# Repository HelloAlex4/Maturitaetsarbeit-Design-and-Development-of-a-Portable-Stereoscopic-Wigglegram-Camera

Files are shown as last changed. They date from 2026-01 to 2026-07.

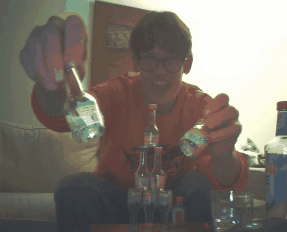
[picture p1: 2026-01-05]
sample_Images/wigglegram1.gif

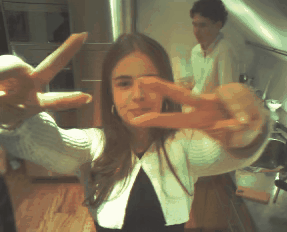
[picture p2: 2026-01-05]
sample_Images/wigglegram3.gif

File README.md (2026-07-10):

# Design and Development of a Portable Stereoscopic Wigglegram Camera

### !!!THIS IS NOT THE CURRENT VERSION OF MERGED.CAMERA, YOU SHOULD NOT COPY THIS BUILD!!!

**Author:** Alexander Rieser

**Project Type:** Maturitätsarbeit (25/26)

**Supervisor:** Madlaina Holler

**Expert:** Patrick Habegger

## Abstract

This Maturitätsarbeit details the design, development, and implementation of a custom-built, portable stereoscopic camera capable of capturing animated wigglegrams. While the wigglegram effect has traditionally been limited to specialized analog film cameras or bulky adapters, this project represents the world's first digital wigglegram camera outside of a few private prototypes. The camera utilizes four horizontally aligned camera modules controlled by multiple processors to capture the wigglegrams. The device surpasses most of its initial goals, such as a synchronization between the first and last camera capture of less than 16 ms. This document extensively details both the technical architecture of the device and the development process. Despite multiple identified limitations like the image resolution and quality, the final product serves as a successful proof-of-concept and a baseline for further improvement.

## Project Overview

This project aims to fill a gap in the market by providing a self-contained, handheld device capable of capturing and processing digital stereoscopic images (wigglegrams) without the need for analog film or bulky adapters. The camera captures four simultaneous images from slightly different perspectives and processes them into an animated GIF that loops back and forth to create a 3D depth effect.

## Features

* **Simultaneous Capture:** Utilizes four horizontally aligned OV5640 camera modules with a synchronization delay of less than 16ms between the first and last frame.

* **Digital Workflow:** Instant preview of captured images and on-device processing of wigglegrams.

* **Portable Design:** Handheld, custom 3D-printed ABS housing with anodized aluminum covers.

* **Touchscreen Interface:** Integrated display running a Flutter-based UI for live preview, gallery browsing, and settings.

* **Battery Power:** Integrated 2-cell Li-ion battery with USB-C charging and telemetry.

## System Architecture

The device is built on a multi-PCB architecture governed by a Raspberry Pi Compute Module 4 and four STM32 microcontrollers.

### Hardware

* **Main PCB:** Acts as the central hub connecting the Raspberry Pi CM4 and the four STM32H743VIT6 microcontrollers. It manages high-speed USB communication and connects the camera modules via DCMI.

* **Power PCB:** Manages power distribution, converting battery voltage (7.2V - 7.8V) into regulated rails (5V, 3.3V, 2.8V, 1.5V). It handles USB-C power negotiation and battery charging.

* **Sensors:** 4x OV5640 Camera Modules arranged with a fixed lens-to-lens distance.

### Software Stack

The software is distributed across three primary layers:

1. **User Interface (Flutter):** Handles user interactions, live preview rendering, and the image gallery on the Raspberry Pi.

2. **Background Processes (Python/C):** Runs on the Raspberry Pi; manages camera synchronization, image processing (GIF generation), and hardware interfacing (fan control, battery monitoring).

3. **Embedded Firmware (C/C++):** Runs on the four STM32 microcontrollers; handles low-level hardware abstraction, DCMI interfacing, and image transmission via USB.

## Development & Testing

The project utilized a "fail-fast" empirical approach, prioritizing rapid physical prototyping. Testing confirmed the camera achieves a between-frame capture time of less than 16ms, ensuring sharp images even with moving subjects. The assembly features a modular design with a 3D-printed chassis and custom heat-dissipation solutions.

## License

[Attribution-NonCommercial 4.0 International]

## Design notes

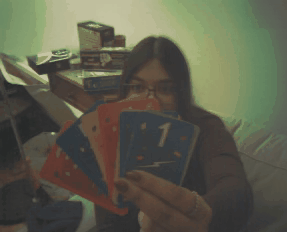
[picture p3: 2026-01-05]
sample_Images/wigglegram5.gif

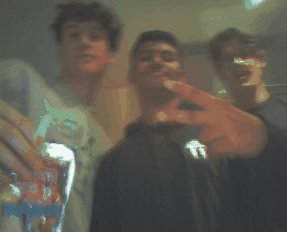
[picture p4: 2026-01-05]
sample_Images/wigglegram6.gif

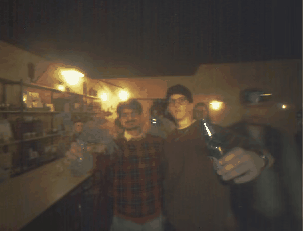
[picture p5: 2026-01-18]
sample_Images/wigglegram10.gif

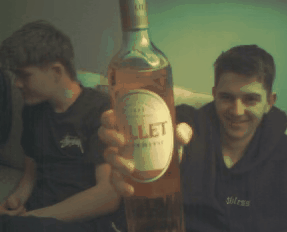
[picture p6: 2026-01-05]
sample_Images/wigglegram4.gif

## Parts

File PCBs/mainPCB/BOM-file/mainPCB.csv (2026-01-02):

Id | Designator | Footprint | Quantity | Designation | Supplier and ref
1 | R22,R38,R7,R5,R17,R8,R49,R14,R15,R9,R45,R25,R32,R21,R13,R6,R30,R33,R16,R37,R51,R12,R48,R10,R29,R20,R18,R24,R40,R41,R46,R27,R61,R42,R34,R62,R64,R50,R26,R43,R35,R63 | R_0603_1608Metric | 42 | 10k
2 | C88,C84,C45,C91,C107,C42,C63,C65,C86,C114,C68,C40,C109,C38,C61,C111,C131,C135,C134 | C_0805_2012Metric | 19 | 1uF
3 | FB6,FB8,FB10,FB2,FB12,FB5,FB1,FB4,FB7,FB3,FB9,FB11,FB14 | R_0805_2012Metric | 13 | FerriteBead
4 | U1 | SOT-23-5 | 1 | TLV70012_SOT23-5
5 | C27,C26,C21,C25,C81,C59,C4,C16,C85,C36,C2,C15,C58,C110,C105,C67,C90,C112,C64,C89,C14,C87,C39,C35,C6,C41,C5,C19,C113,C62,C1,C108,C44,C104,C66,C22,C82,C43,C136,C32,C133,C101,C78,C55,C130 | C_0402_1005Metric | 45 | 0.1uF
6 | C47,C93,C70,C7,C115,C46,C60,C106,C20,C83,C37,C28,C116,C69,C92,C132 | C_0805_2012Metric | 16 | 10uF
7 | C71,C95,C49,C76,C94,C30,C72,C52,C53,C29,C117,C98,C48,C75,C99,C118 | C_0603_1608Metric | 16 | 17pF
8 | Y8,Y5,Y11,Y14 | Crystal_SMD_3215-2Pin_3.2x1.5mm | 4 | Crystal
9 | R4,R1,R2,R3 | R_0603_1608Metric | 4 | 20Ohm
10 | J8,J10,J14,J12 | PinHeader_1x06_P2.54mm_Vertical | 4 | Conn_01x06_Pin
11 | J3 | HDMI_A_Molex_208658-1001_Horizontal | 1 | HDMI_A
12 | Y3,Y2 | Crystal_SMD_2016-4Pin_2.0x1.6mm | 2 | Crystal
13 | C80,C56,C34,C33,C103,C102,C57,C79,C97,C74,C96,C119,C51,C73,C120,C50 | C_0805_2012Metric | 16 | 2.2uF
14 | C54,C100,C3,C31,C77,C13,C8,C9,C11,C10,C12 | C_0402_1005Metric | 11 | 1uF
15 | J1,J2 | PinSocket_1x07_P2.54mm_Vertical | 2 | Conn_01x07_Pin
16 | J16 | PinHeader_1x04_P2.00mm_Horizontal | 1 | Conn_01x04
17 | U8 | SSOP-16_GL823K-HCY04_GEN | 1 | GL823K-HCY04
18 | J5,J17 | cm4100pinconnector | 2 | DF40C-100DS-0.4V_51_
19 | U11,U12,U13,U10 | LQFP-100_14x14mm_P0.5mm | 4 | STM32H743VITx
20 | C17,C23,C24 | C_0603_1608Metric | 3 | 15pF
21 | U2 | TSSOP-8_4.4x3mm_P0.65mm | 1 | CDCV304
22 | R31,R23,R39,R47 | C_0603_1608Metric | 4 | R_Small
23 | Y1,Y16 | Crystal_SMD_3225-4Pin_3.2x2.5mm | 2 | SG-210SCD
24 | Y10,Y4,Y7,Y13 | Crystal_SMD_3225-4Pin_3.2x2.5mm | 4 | Crystal_GND23
25 | J7,J11,J9,J13,J15 | 524372471 | 5 | 52437-2471
26 | U15,U7,U14,U16 | SOT-23-5 | 4 | AAT4610BIGV-1-T1
27 | R19 | R_0402_1005Metric | 1 | R
28 | J6 | CONN_503398-1892_MOL | 1 | SD card slot
29 | R11 | R_0603_1608Metric | 1 | 1.6kOhm
30 | C18 | C_0603_1608Metric | 1 | 18pF
31 | U9 | QFN-36-1EP_6x6mm_P0.5mm_EP3.7x3.7mm | 1 | USB2514B_Bi
32 | IC1 | QFN40P800X800X90-69N-D | 1 | UPD720201K8-701-BAC-A
33 | J4 | USB_C_Receptacle_XKB_U262-16XN-4BVC11 | 1 | USB_C_Receptacle_USB2.0_14P
34 | R52,R36,R28,R44 | R_1206_3216Metric | 4 | R
35 | Y6,Y15,Y9,Y12 | Oscillator_SMD_Kyocera_KC2520Z-4Pin_2.5x2.0mm | 4 | SG-210SCD
36 | IC3,IC2,IC5,IC4 | usb3320 | 4 | USB3320C-EZK-TR
37 | U5 | SOT-223-3_TabPin2 | 1 | AMS1117-1.5
38 | U6 | SOT-23-5 | 1 | TLV75728PDBV
39 | U4 | SOT-223-3_TabPin2 | 1 | BL8072CLTR33

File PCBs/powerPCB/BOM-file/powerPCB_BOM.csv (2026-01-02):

Id | Designator | Footprint | Quantity | Designation | Supplier and ref
1 | D1 | D_SMA | 1 | SS38
2 | U4,U2 | SOT-23-5 | 2 | MICRONE(Nanjing Micro One Elec) ME6212C28M5G
3 | C40,C21,C19,C43,C15,C42,C12,C20,C16 | C_0402_1005Metric | 9 | 0.1uF
4 | C138,C66,C141,C67,C65,C64,C137 | C_0805_2012Metric | 7 | 1uF
5 | U1 | QFN65P400X400X90-17N | 1 | TP5100
6 | U10 | SOP50P490X110-10N | 1 | INA226AIDGSR
7 | L2 | L_Changjiang_FXL0630 | 1 | 10uH
8 | U11 | SOT-223-3_TabPin2 | 1 | 5v to 3.3v converter
9 | D6 | LED_0805_2012Metric | 1 | LED
10 | L1 | L_APV_APH0530 | 1 | 4.7uH inductor
11 | D7 | LED_0603_1608Metric | 1 | LED
12 | U9 | TO-263-7_TabPin8 | 1 | LM22678TJ-5.0/NOPB
13 | C36,C38 | C_0603_1608Metric | 2 | 6.8uF
14 | R25 | R_2512_6332Metric | 1 | R_Shunt
15 | C39,C41,C44 | C_0805_2012Metric | 3 | 10uF
16 | J2,J1 | PinHeader_1x07_P2.54mm_Vertical | 2 | Conn_01x07_Pin
17 | R23 | R_0603_1608Metric | 1 | 470Ohm
18 | C37 | CP_Elec_6.3x5.9 | 1 | 180uF
19 | R19 | R_0603_1608Metric | 1 | 10k
20 | C4,C5 | C_0805_2012Metric | 2 | 22uF
21 | R13 | R_1206_3216Metric | 1 | 0.06Ohm
22 | U3 | SOT-23-5 | 1 | Diodes Incorporated AP2112K-1.8TRG1
23 | R20 | R_0603_1608Metric | 1 | 7.5kOhm
24 | R14 | R_1206_3216Metric | 1 | 3 Ohm
25 | C22 | C_0603_1608Metric | 1 | 10nF
26 | SW1 | SW_Slide_SPDT_Angled_CK_OS102011MA1Q | 1 | SW_DPST_x2
27 | IC1 | SON50P300X300X80-11N-D | 1 | HUSB238
28 | D5 | D_SMA | 1 | D_Filled

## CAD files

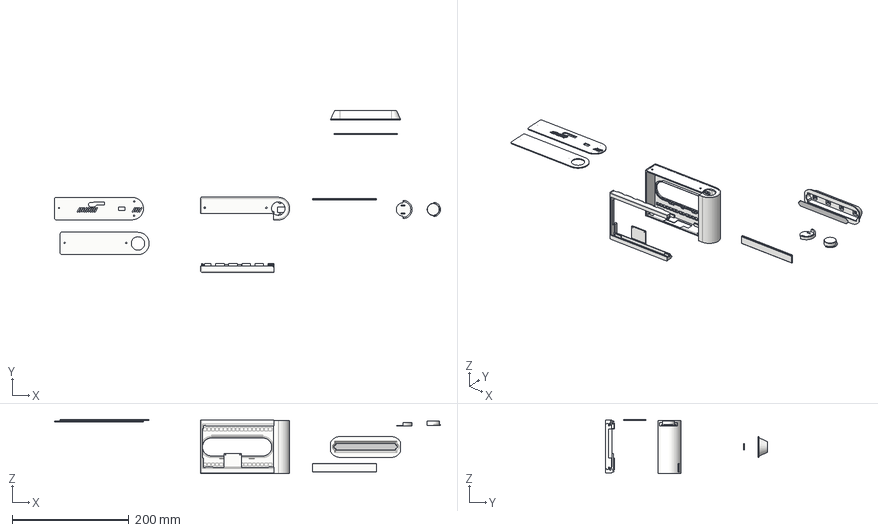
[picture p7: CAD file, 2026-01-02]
3d-models_and_drawings/3d-files (.step-.f3d)/allComponents.step
660.9 x 277.5 x 92.6 mm
cameraHold
topPlate
bottomPlate
button
ButtonPlug

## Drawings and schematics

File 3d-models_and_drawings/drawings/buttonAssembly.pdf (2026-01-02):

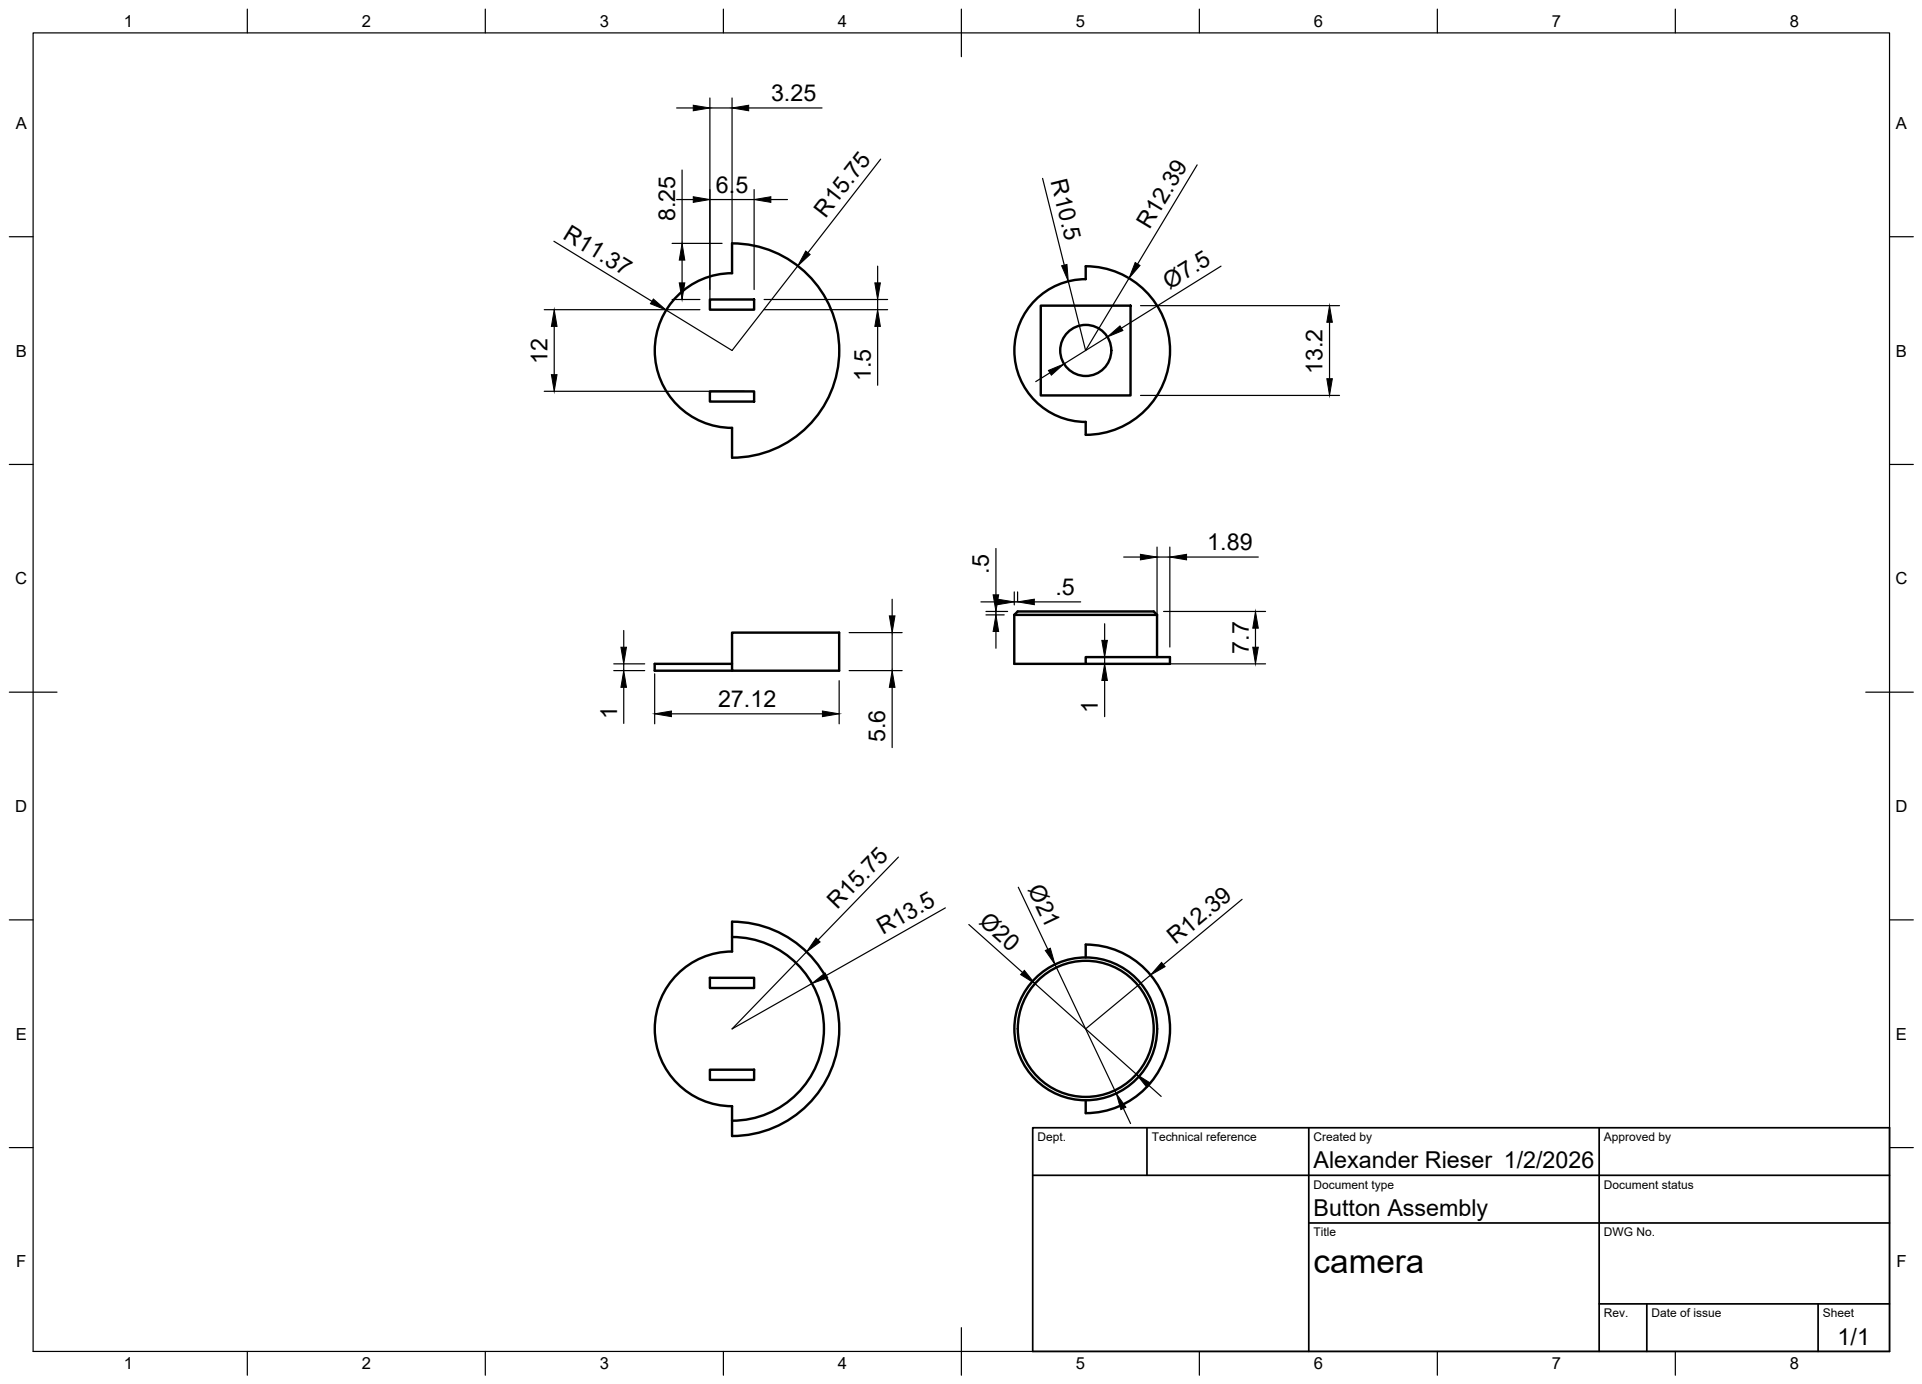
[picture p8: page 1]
Title; DWG No.; Rev.; Date of issue; Sheet

Dept. | Technical reference | Created by Alexander Rieser 1/2/2026 | Approved by

Document type Button Assembly | Document status

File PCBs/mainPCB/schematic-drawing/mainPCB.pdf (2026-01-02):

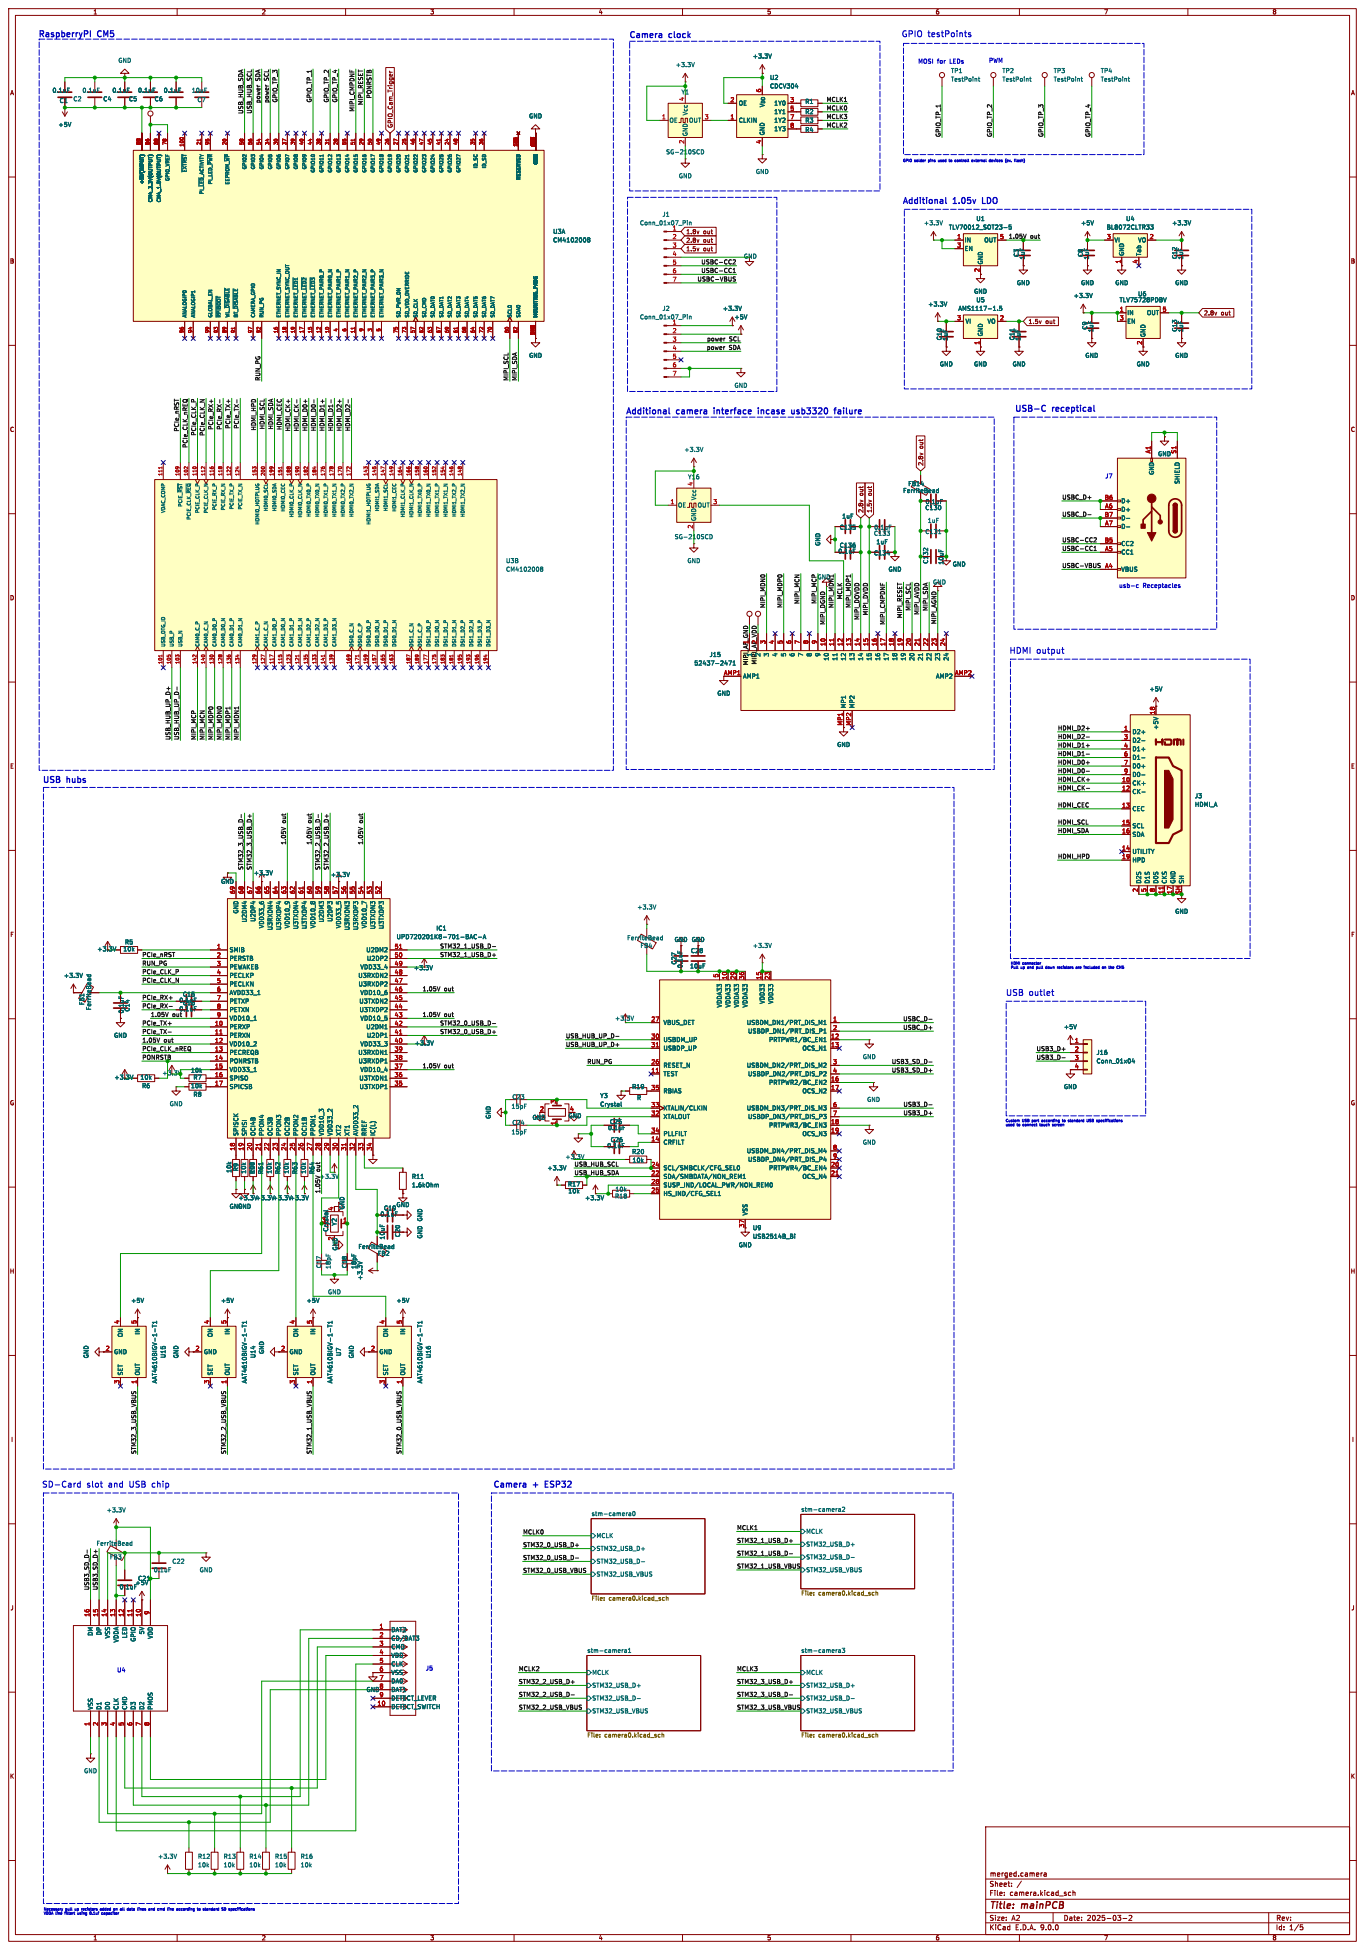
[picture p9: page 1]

5 SD_PWR_ON 75 SD_VDD_OVERRIDE 73 SD_CLK 57 SD_CMD 62 SD_DAT0 63 SD_DAT1 67 SD_DAT2 69 SD_DAT3 61 SD_DAT4 68 SD_DAT5 64 SD_DAT6 72 SD_DAT7 70 SCL0 80 SDA0 82 MOUNTING_PADS SH1234 +5V(INPUT) 7798135 CM4_3.3V(OUTPUT) 846 CM4_1.8V(OUTPUT) 8890 GPIO_VREF 78 ~{EXTRST} 100 PI_~{LED}_ACTIVITY 21 PI_LED_~{PWR} 95 EEPROM_~{WP} 20 GPIO2 58 GPIO3 56 GPIO4 54 GPIO5 34 GPIO6 30 GPIO7 37 GPIO8 39 GPIO9 40 GPIO10 44 GPIO11 38 GPIO12 31 GPIO13 28 GPIO14 55 GPIO15 51 GPIO16 29 GPIO17 50 GPIO18 49 GPIO19 26 GPIO20 27 GPIO21 25 GPIO22 46 GPIO23 47 GPIO24 45 GPIO25 41 GPIO26 24 GPIO27 48 ID_SC 35 ID_SD 36 RESERVED 1046 76 GND

2 OUT 5 C9 1uF GND C13 1uF GND GND
+3.3V GND

9 10 10 11 11 12 12 MP1 MP1 13 13 MP2 MP2 14 14 15 15 16 16 17 17 18 18 19 19 20 20 21 21 22 22 23 23 24 24 AMP2 AMP2 C132 10uF GND GND GND GND

D2+ 1 D2- 3 D1+ 4 D1- 6 D0+ 7 D0- 9 CK+ 10 CK- 12 CEC 13 SCL 15 SDA 16 UTILITY 14 HPD 19 D2S

J3HDMI_A D2+ 1 D2- 3 D1+ 4 D1- 6 D0+ 7 D0- 9 CK+ 10 CK- 12 CEC 13 SCL 15 SDA 16 UTILITY 14 HPD 19 D2S

8 CKS 11 GND 17 SH SH

File: camera.kicad_sch Sheet: / merged.camera MCLK
STM32_USB_D+ STM32_USB_D- STM32_USB_VBUS

8 VSS 14 VDDA 13 LED 12 GPIO 11 5V 10 VDD

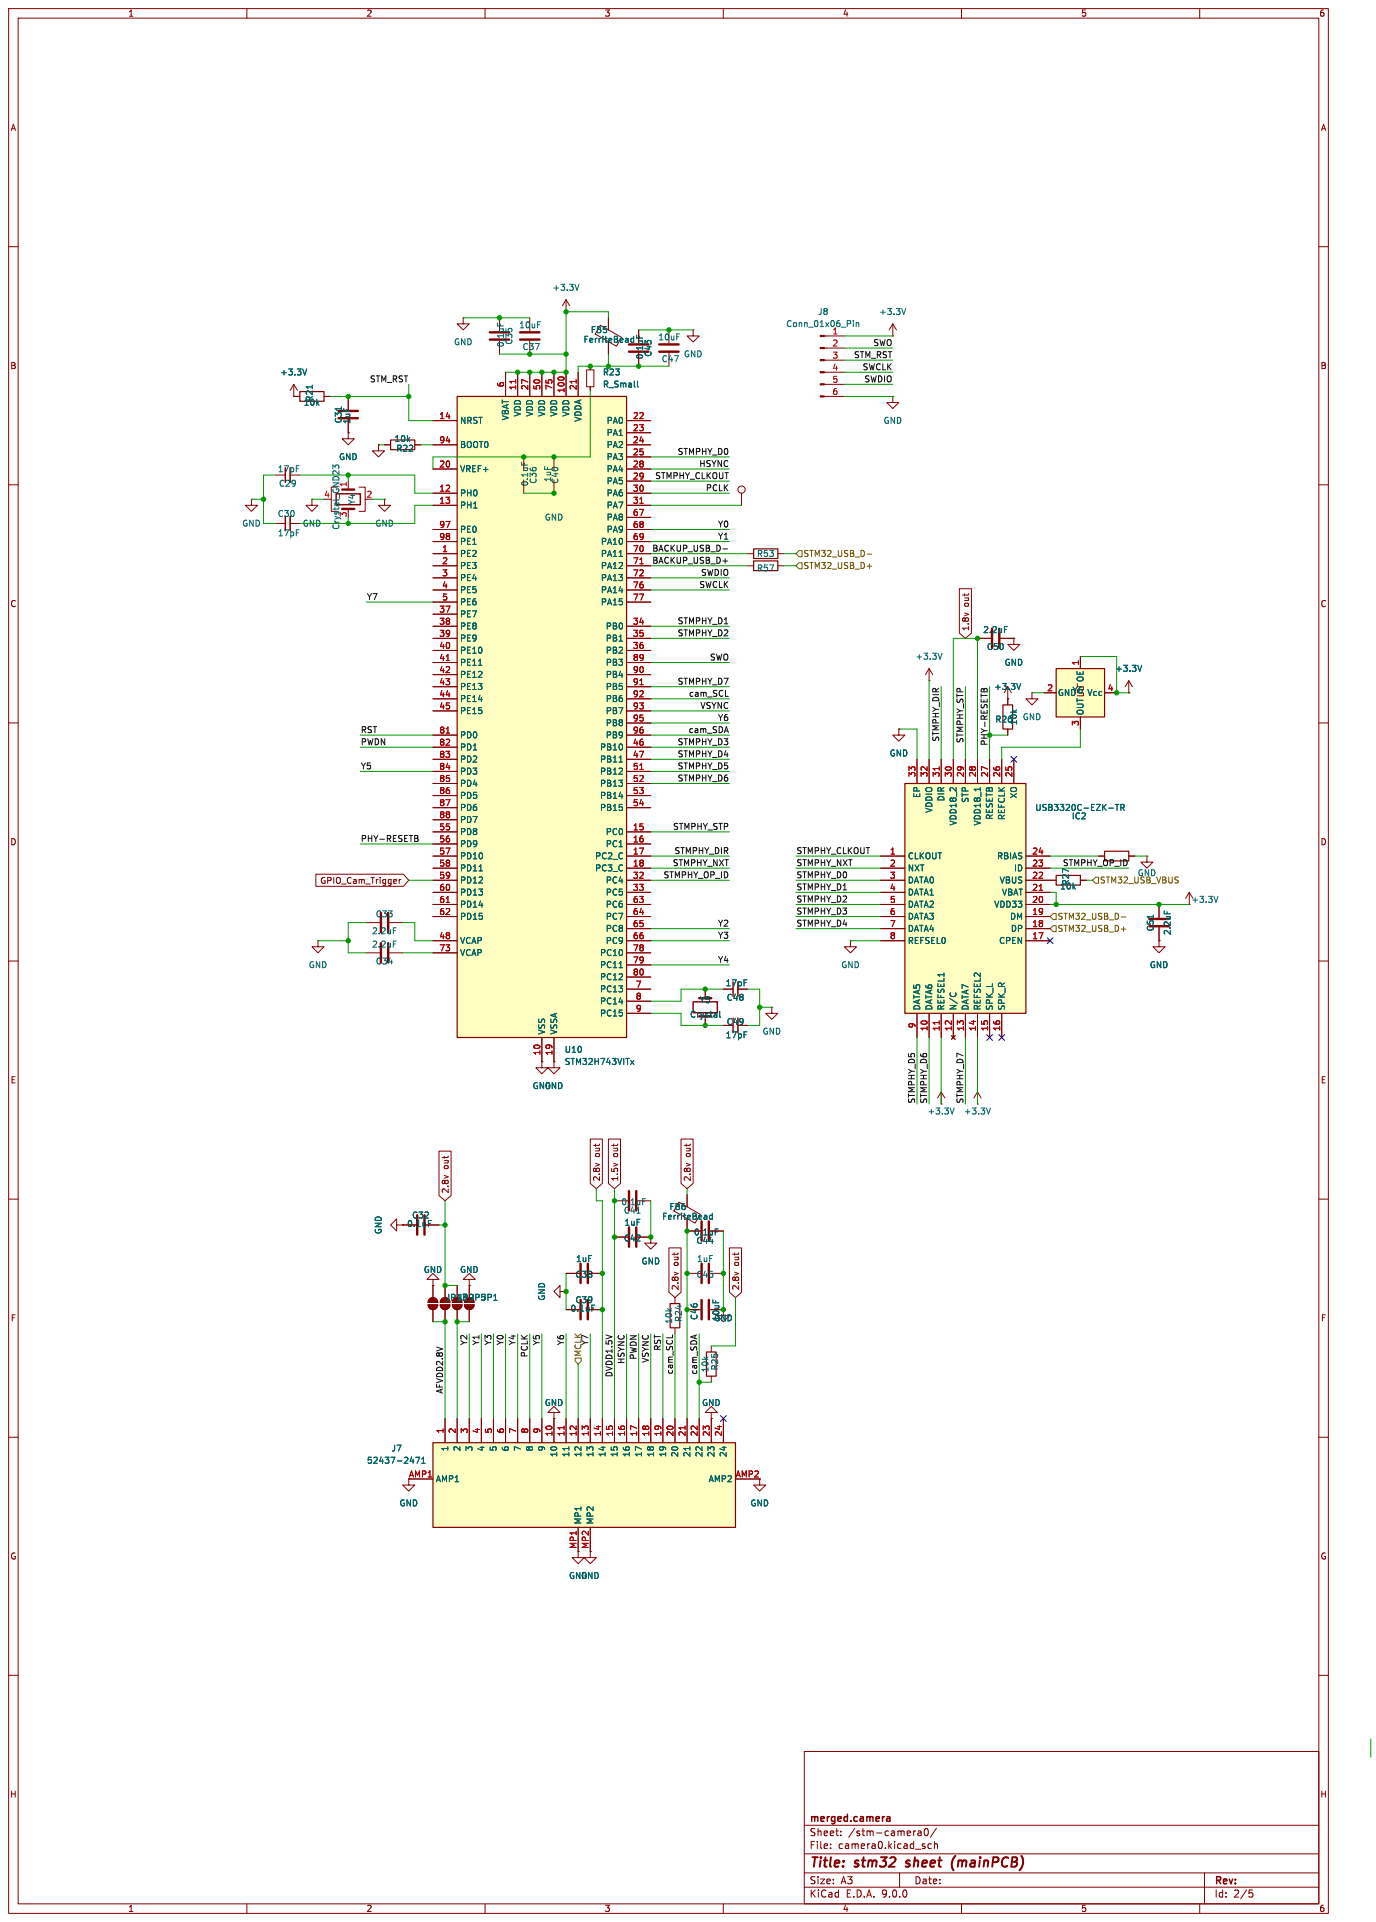
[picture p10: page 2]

6 VDD 11 VDD 27 VDD 50 VSS 10 VDD 75 VSSA 19 VDD 100 VDDA 21 PA0 22 PA1 23 PA2 24 PA3 25 PA4 28 PA5 29 PA6 30 PA7 31 PA8 67 PA9 68 PA10 69 PA11 70 PA12 71 PA13 72 PA14 76 PA15 77 PB0 34 PB1 35 PB2 36 PB3 89 PB4 90 PB5 91 PB6 92 PB7 93 PB8 95 PB9 96 PB10 46 PB11 47 PB12 51 PB13 52 PB14 53 PB15 54 PC0 15 PC1 16 PC2_C 17 PC3_C 18 PC4 32 PC5 33 PC6 63 PC7 64 PC8 65 PC9 66 PC10 78 PC11 79 PC12 80 PC13 7 PC14 8 PC15 9 U10 STM32H743VITx

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

9 VDDIO 32 DATA6 10 DIR 31 REFSEL1 11 VDD18_2 30 N/C 12 STP 29 DATA7 13 VDD18_1 28 REFSEL2 14 RESETB 27 SPK_L 15 REFCLK 26 SPK_R 16 XO 25 RBIAS 24

9 10 10 11 11 12 12 13 13 14 14 15 15 16 16 17 17 18 18 19 19 20 20 21 21 22 22 24 24 23 23 P1 FPC 0.5MM 22P Pull type H2.0mm Under the next C41
1uF GND

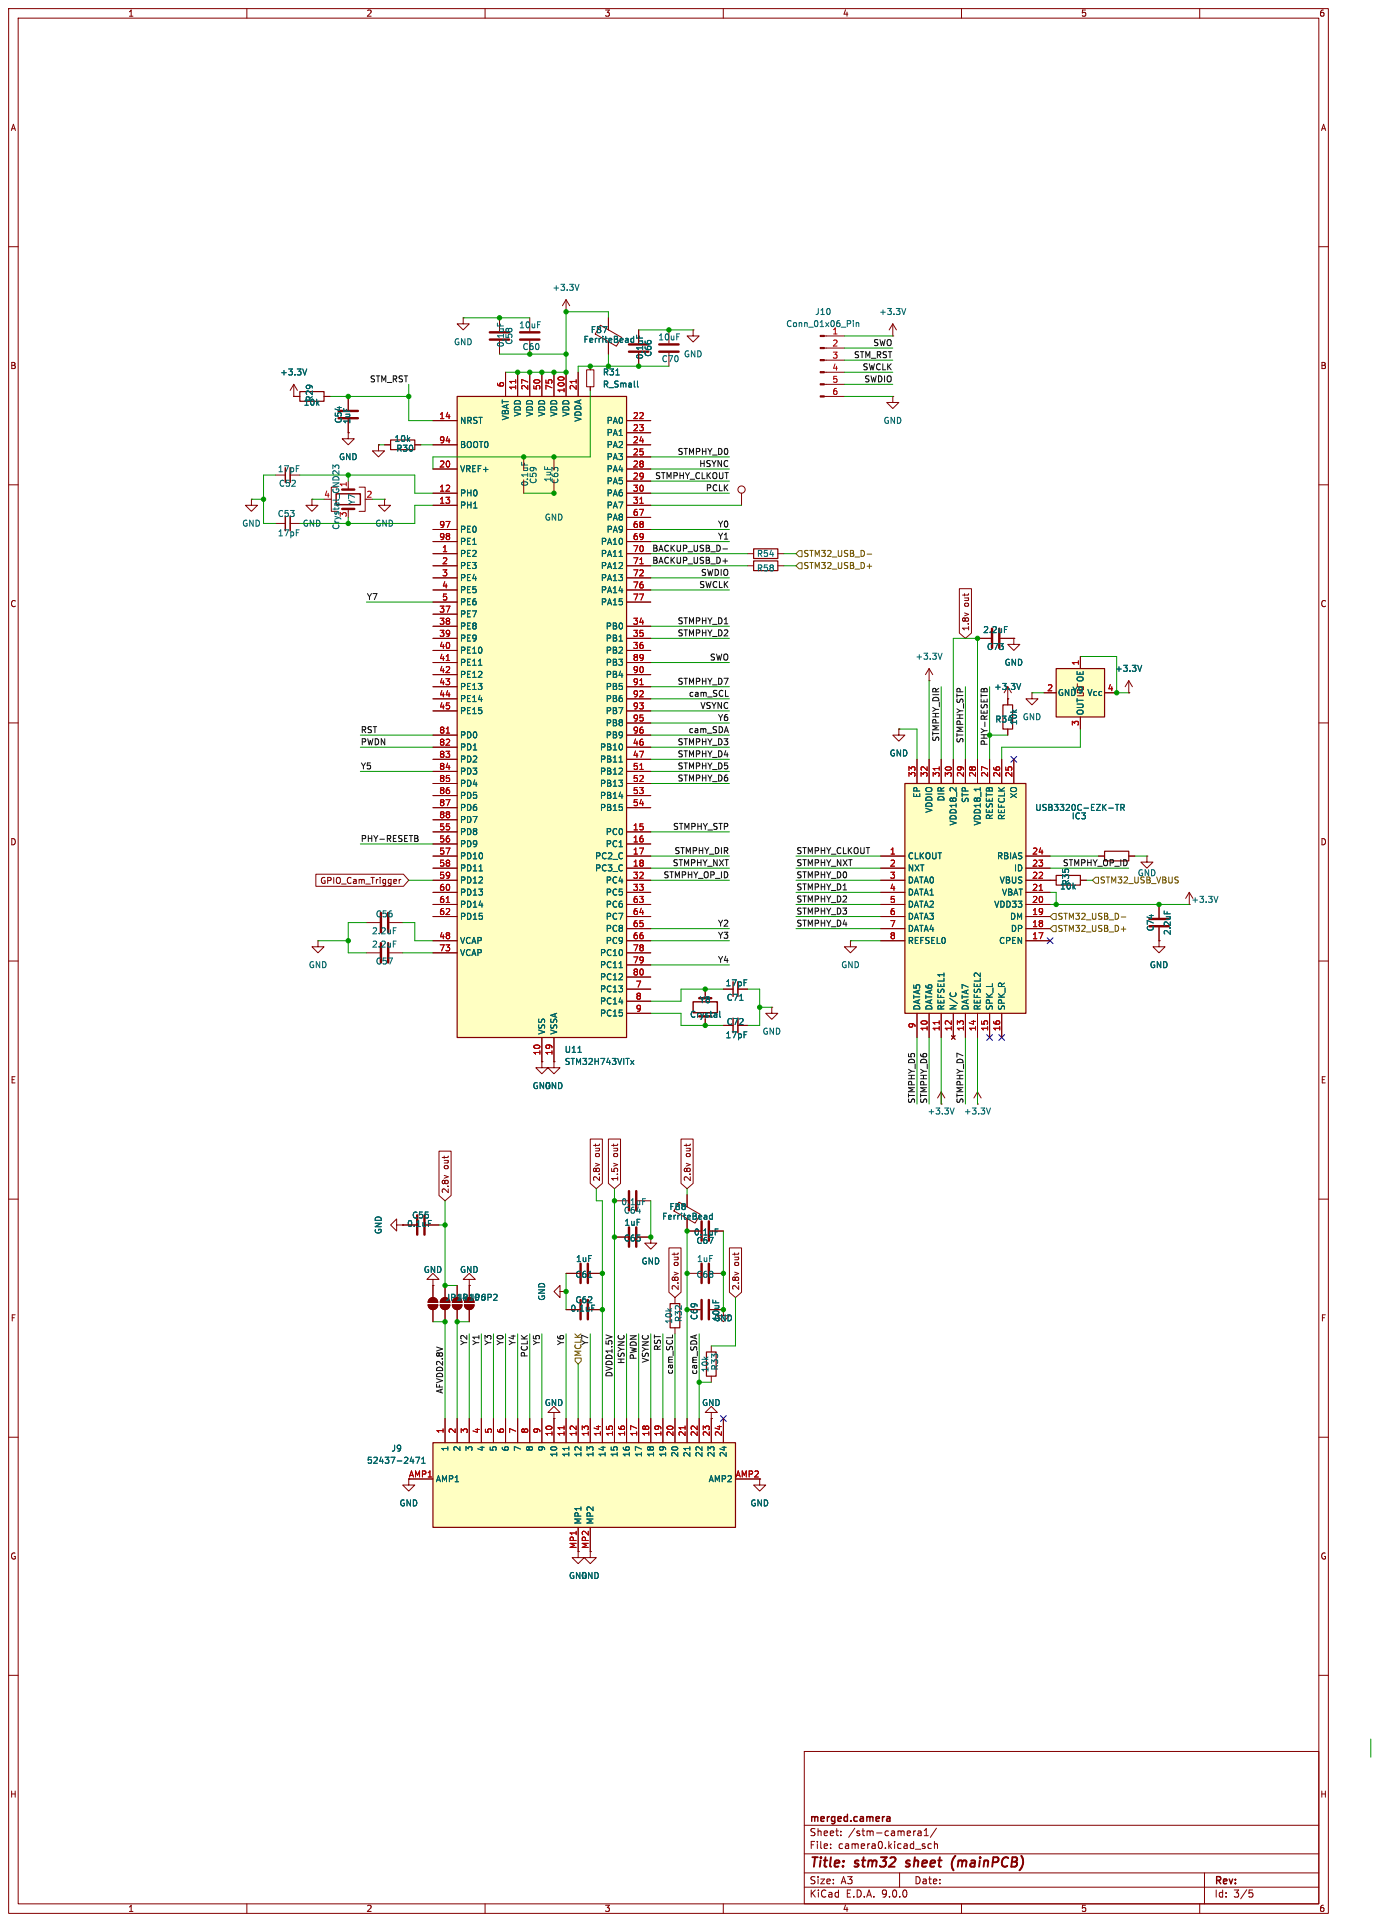
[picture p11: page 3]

6 VDD 11 VDD 27 VDD 50 VSS 10 VDD 75 VSSA 19 VDD 100 VDDA 21 PA0 22 PA1 23 PA2 24 PA3 25 PA4 28 PA5 29 PA6 30 PA7 31 PA8 67 PA9 68 PA10 69 PA11 70 PA12 71 PA13 72 PA14 76 PA15 77 PB0 34 PB1 35 PB2 36 PB3 89 PB4 90 PB5 91 PB6 92 PB7 93 PB8 95 PB9 96 PB10 46 PB11 47 PB12 51 PB13 52 PB14 53 PB15 54 PC0 15 PC1 16 PC2_C 17 PC3_C 18 PC4 32 PC5 33 PC6 63 PC7 64 PC8 65 PC9 66 PC10 78 PC11 79 PC12 80 PC13 7 PC14 8 PC15 9 U11 STM32H743VITx

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

9 10 10 11 11 12 12 13 13 14 14 15 15 16 16 17 17 18 18 19 19 20 20 21 21 22 22 24 24 23 23 P2 FPC 0.5MM 22P Pull type H2.0mm Under the next C65

Id: 3/5 Title: stm32 sheet (mainPCB) File: camera0.kicad_sch Sheet: /stm-camera1/ merged.camera

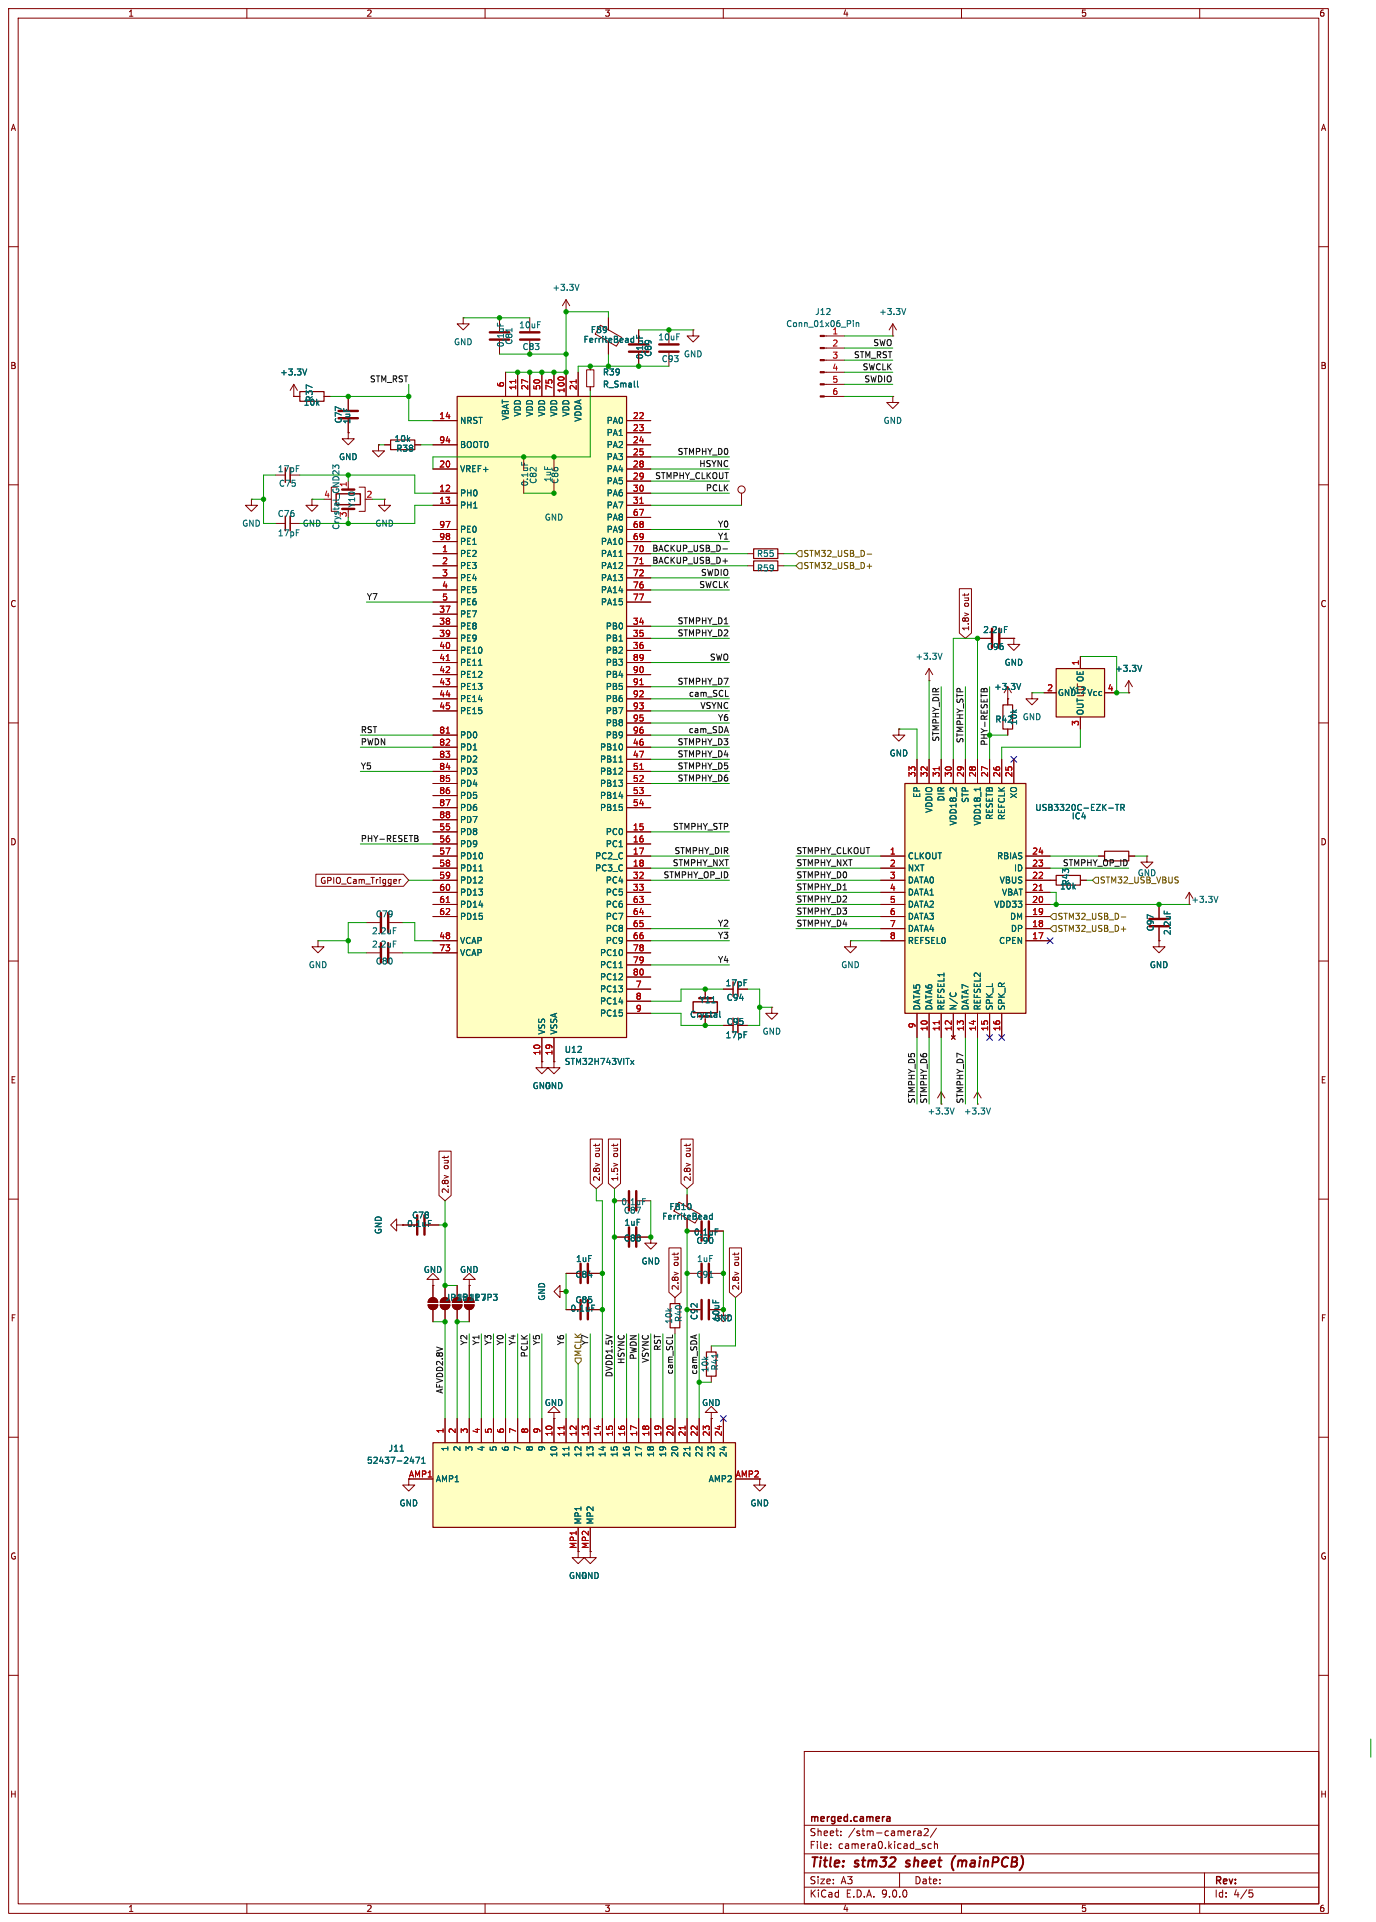
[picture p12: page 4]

6 VDD 11 VDD 27 VDD 50 VSS 10 VDD 75 VSSA 19 VDD 100 VDDA 21 PA0 22 PA1 23 PA2 24 PA3 25 PA4 28 PA5 29 PA6 30 PA7 31 PA8 67 PA9 68 PA10 69 PA11 70 PA12 71 PA13 72 PA14 76 PA15 77 PB0 34 PB1 35 PB2 36 PB3 89 PB4 90 PB5 91 PB6 92 PB7 93 PB8 95 PB9 96 PB10 46 PB11 47 PB12 51 PB13 52 PB14 53 PB15 54 PC0 15 PC1 16 PC2_C 17 PC3_C 18 PC4 32 PC5 33 PC6 63 PC7 64 PC8 65 PC9 66 PC10 78 PC11 79 PC12 80 PC13 7 PC14 8 PC15 9 U12 STM32H743VITx

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

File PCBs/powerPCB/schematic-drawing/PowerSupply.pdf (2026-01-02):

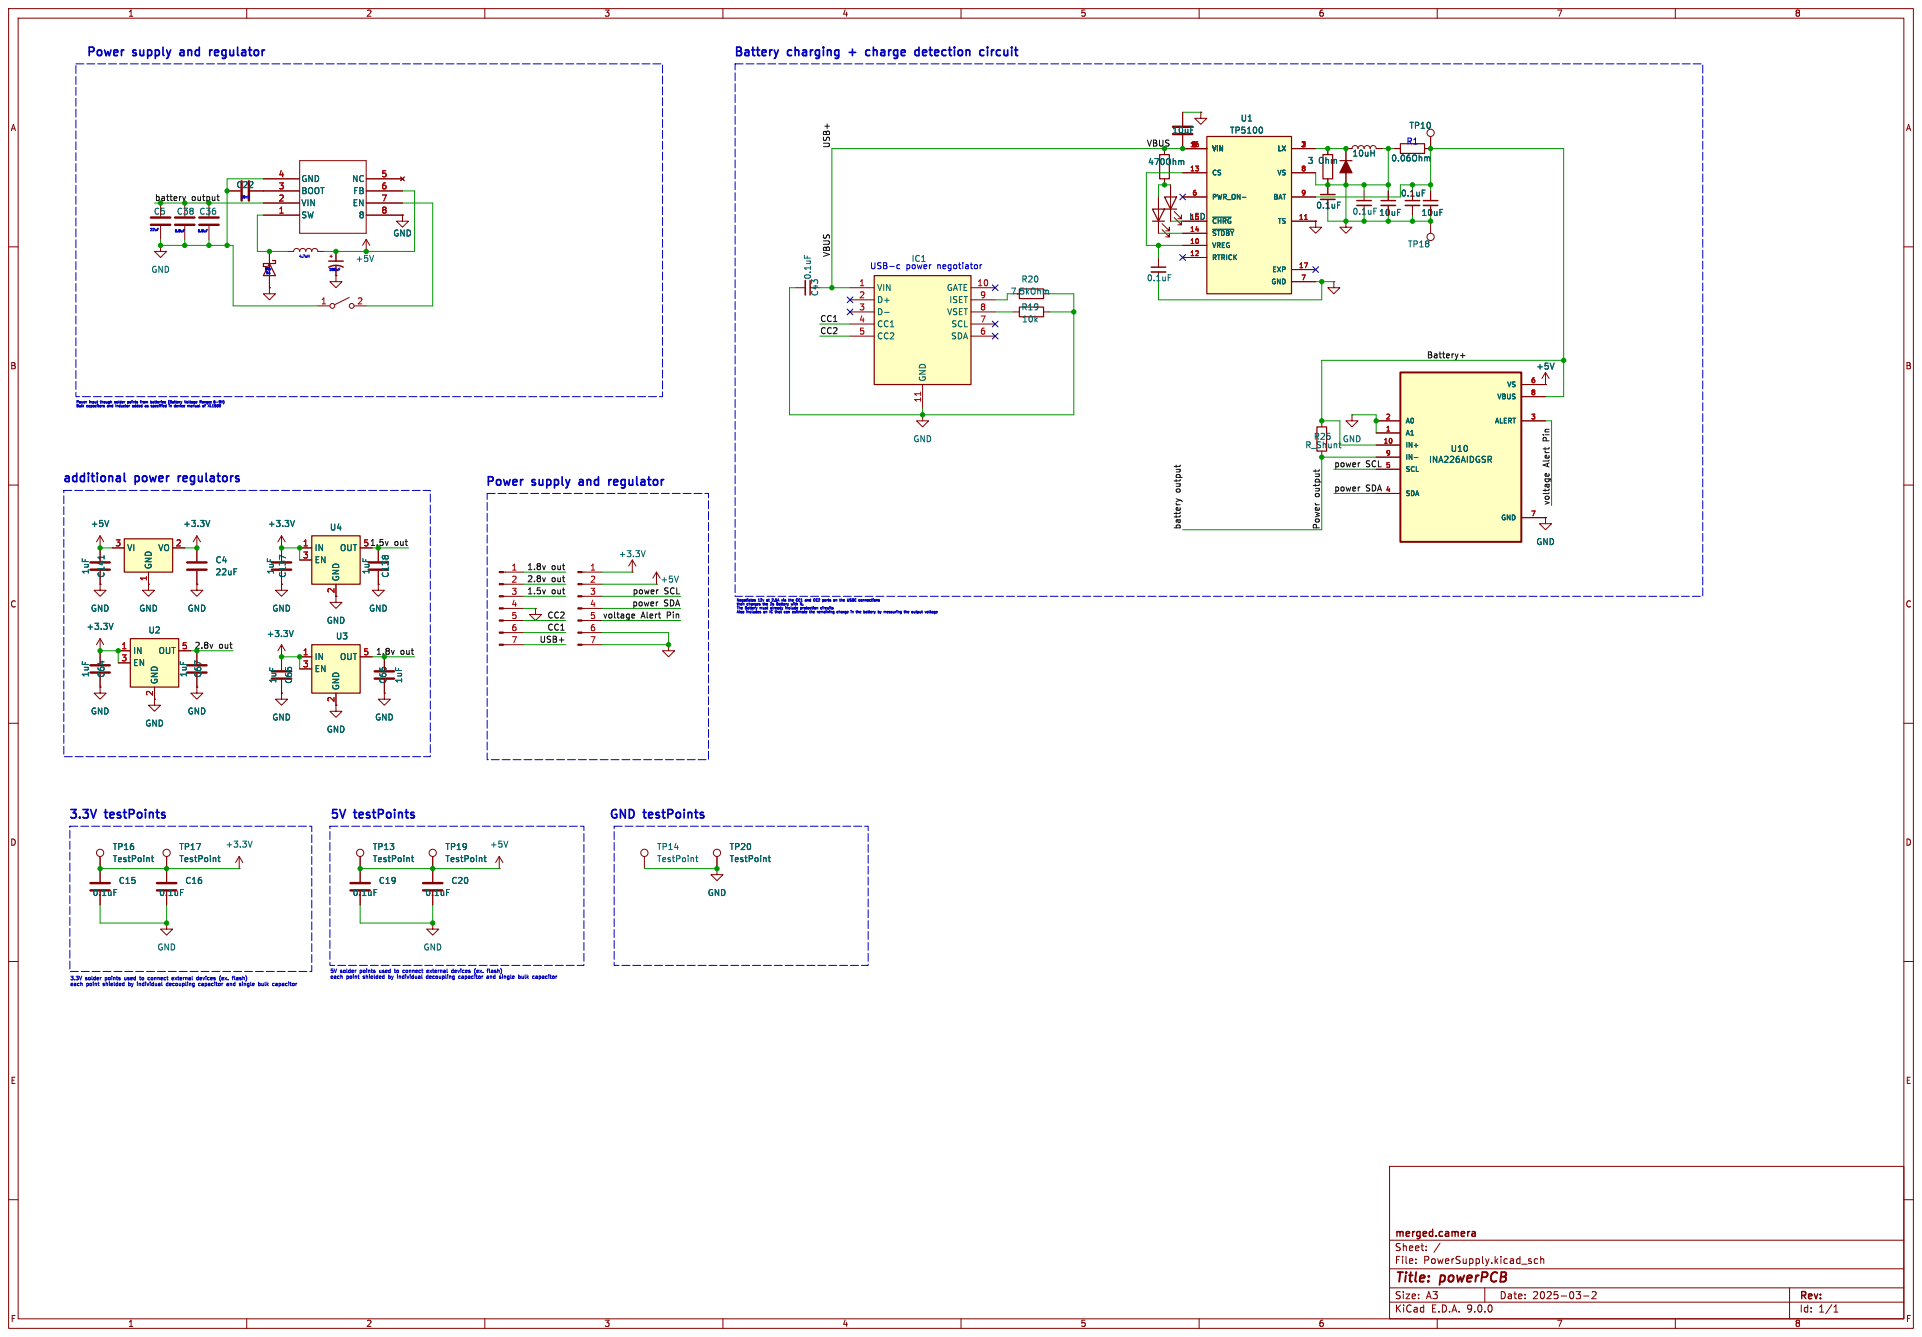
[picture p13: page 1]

Power supply and regulator

2 OUT 5 C138 1uF GND GND GND 1uF C65 C137 1uF

2 OUT 5 GND GND GND

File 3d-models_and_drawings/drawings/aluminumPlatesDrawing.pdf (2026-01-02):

1.99 1.4

2.022.02 | 137.72 R19.2 Ø2.4 | Ø2.4 Ø2.4 17.02 11 | 6 60° R1 ³.66 | 7.2 ¹³.86

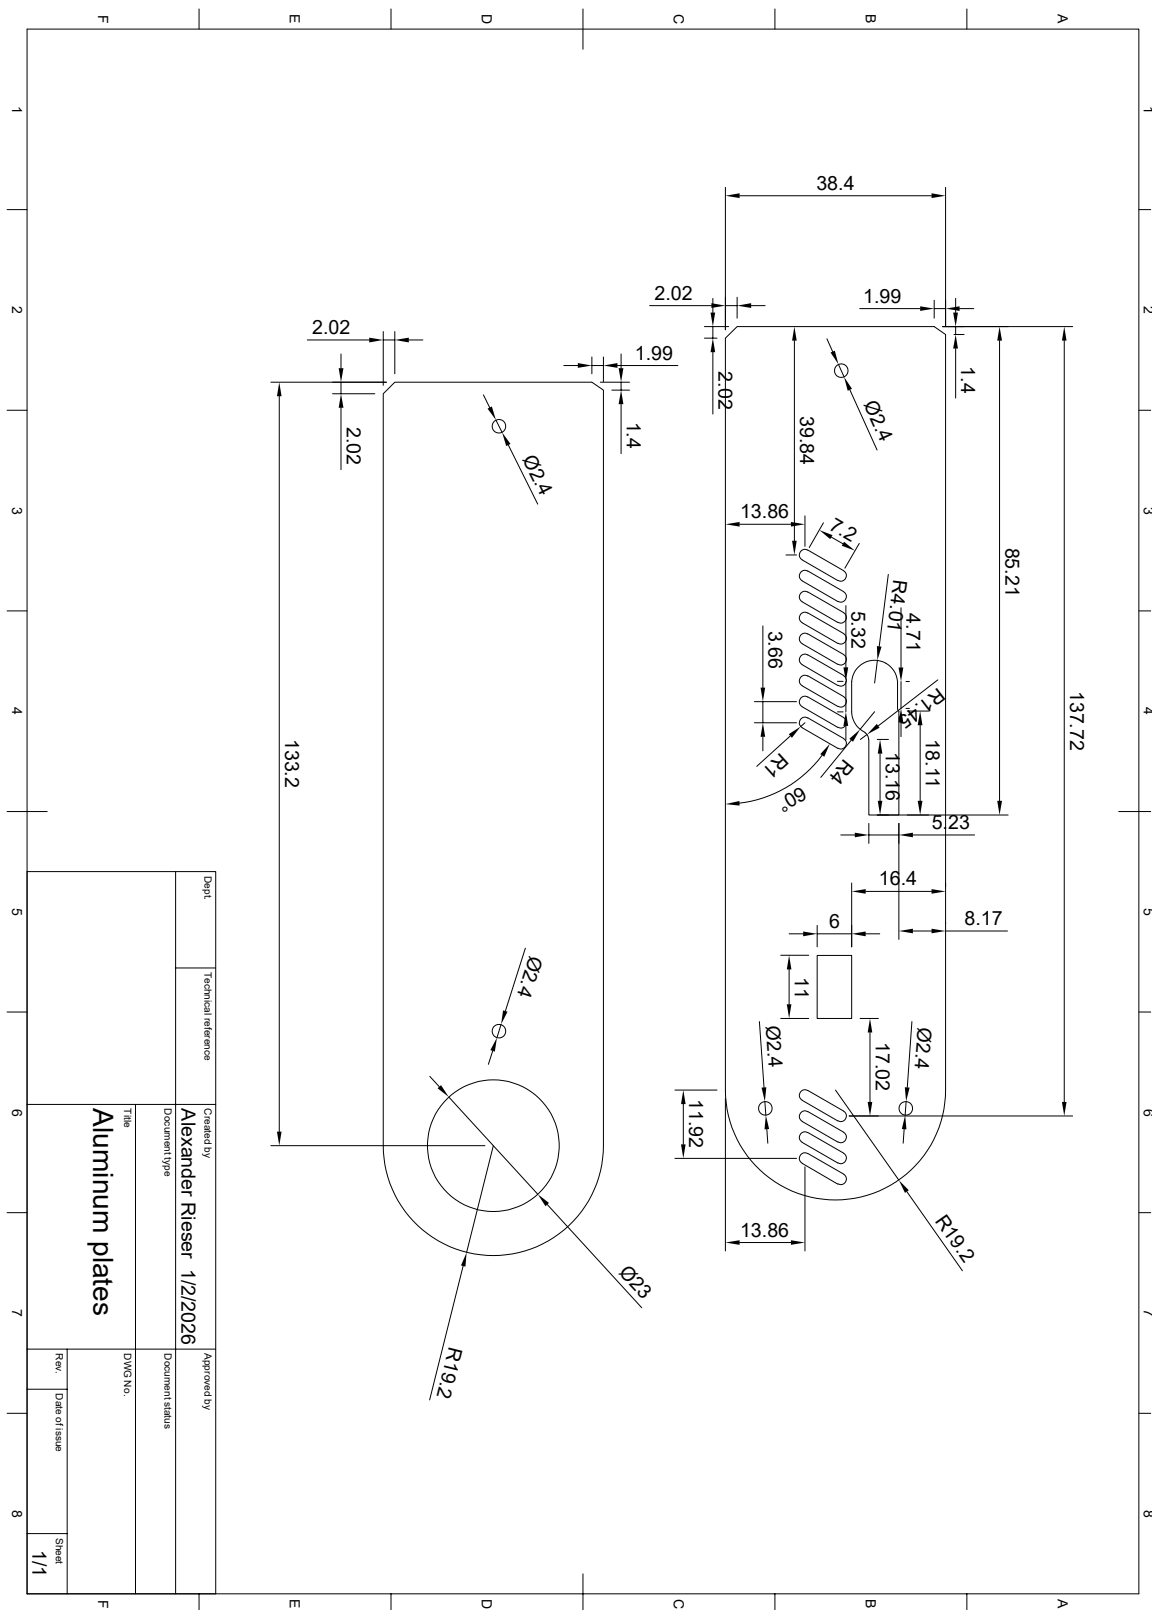
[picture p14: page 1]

1 A 2 3 4 5 6 7 8 1 2 3 4 5 6 7 8 FEDCB FEDCBA Dept. Technical reference Created by Approved by Title DWG No. Document type Document status Rev. Date of issue Sheet 1/2/2026 1/1 Aluminum plates Alexander Rieser 133.2 Ø23 R19.2 Ø2.4 Ø2.4

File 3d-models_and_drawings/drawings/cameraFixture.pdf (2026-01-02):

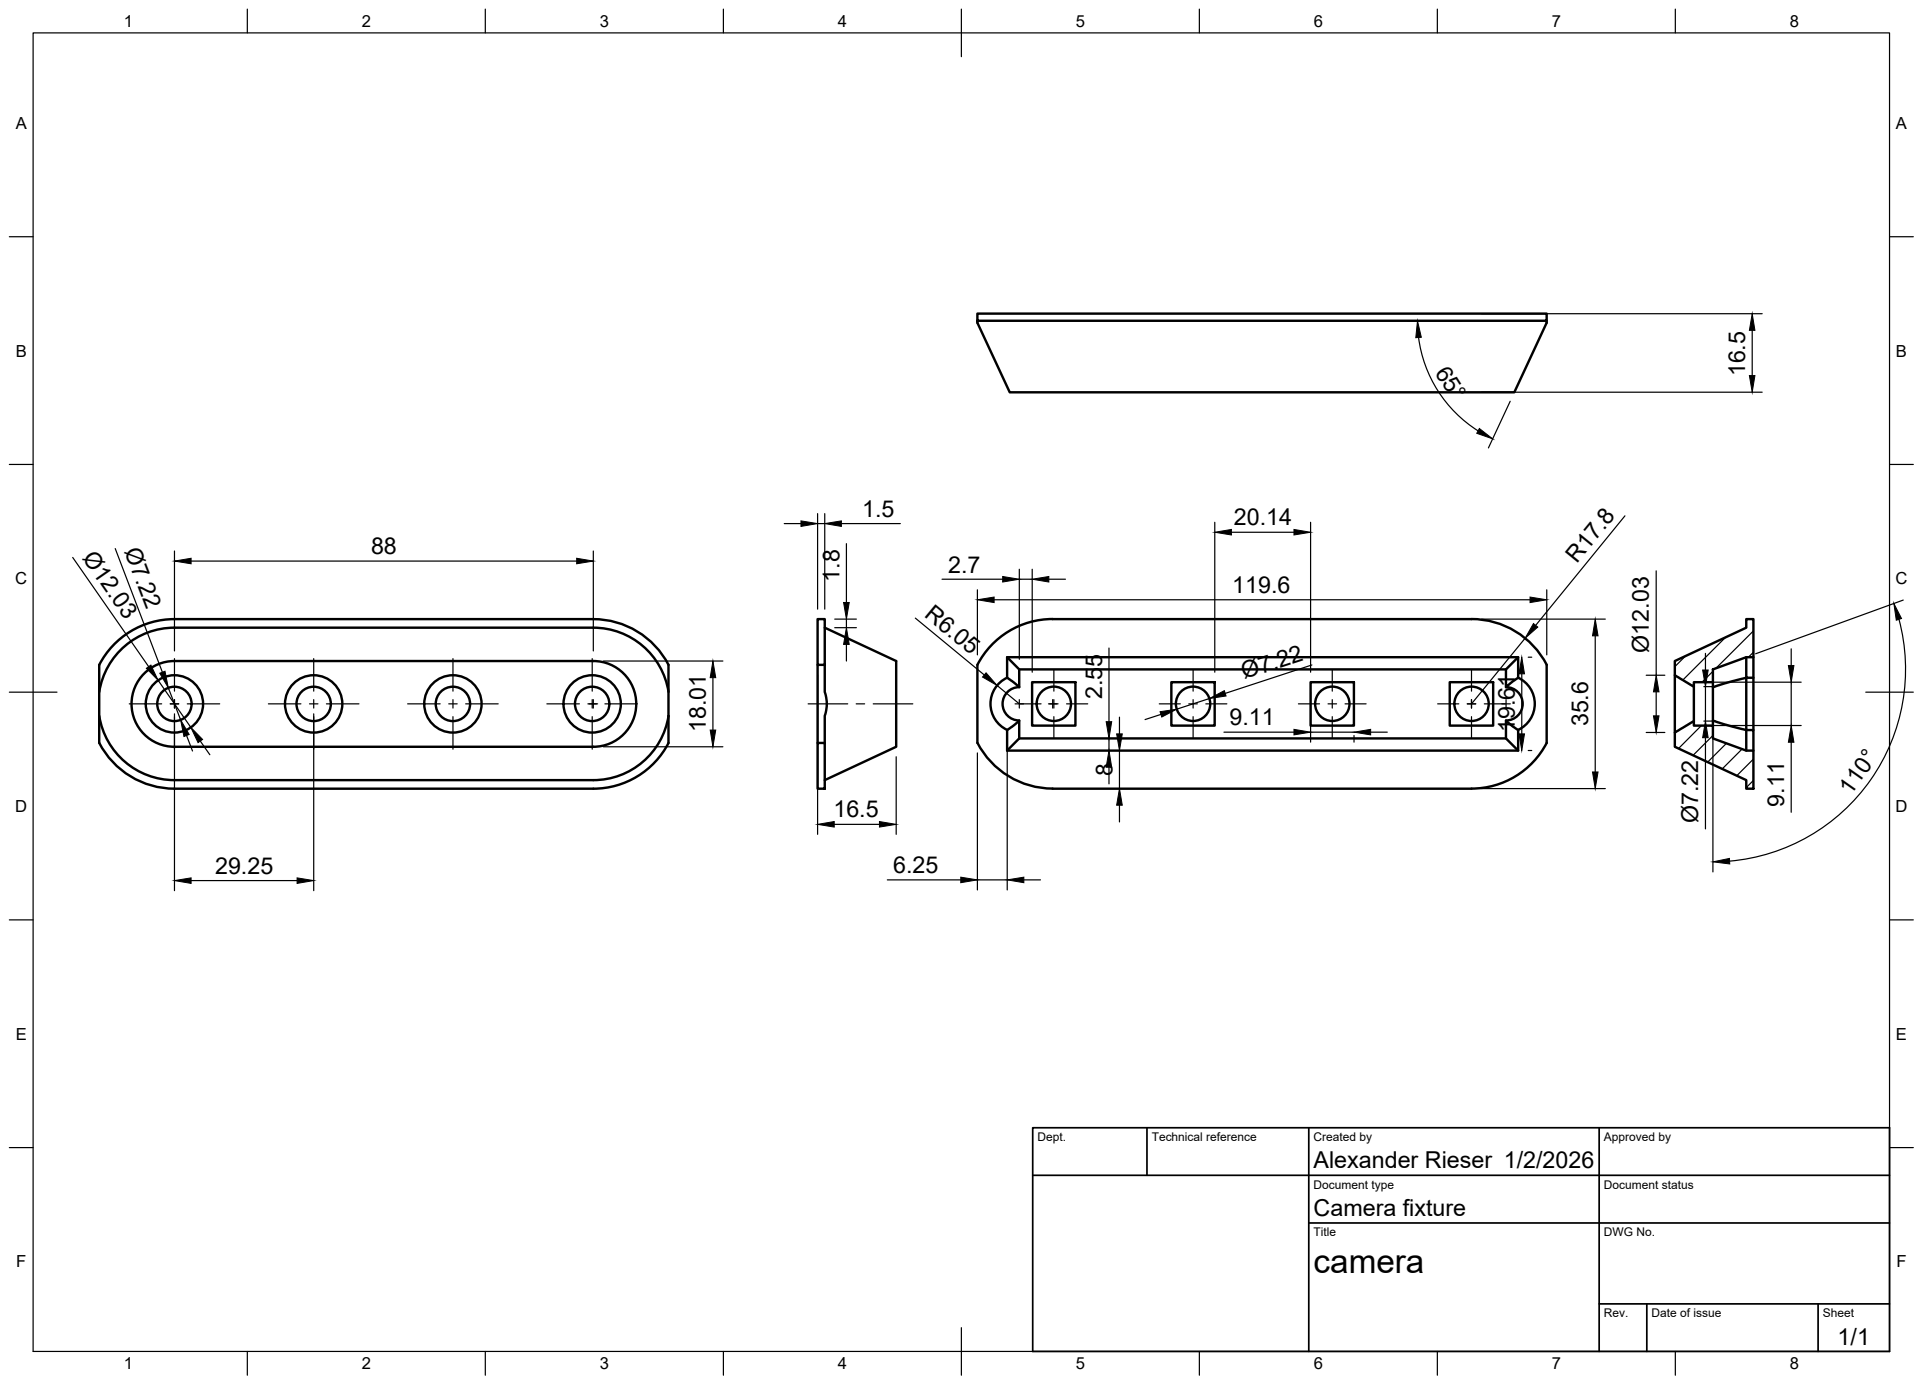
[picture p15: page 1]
Title; DWG No.; Rev.; Date of issue; Sheet; Alexander Rieser

Dept. | Technical reference | Created by 1/2/2026 | Approved by

Document type Camera fixture | Document status

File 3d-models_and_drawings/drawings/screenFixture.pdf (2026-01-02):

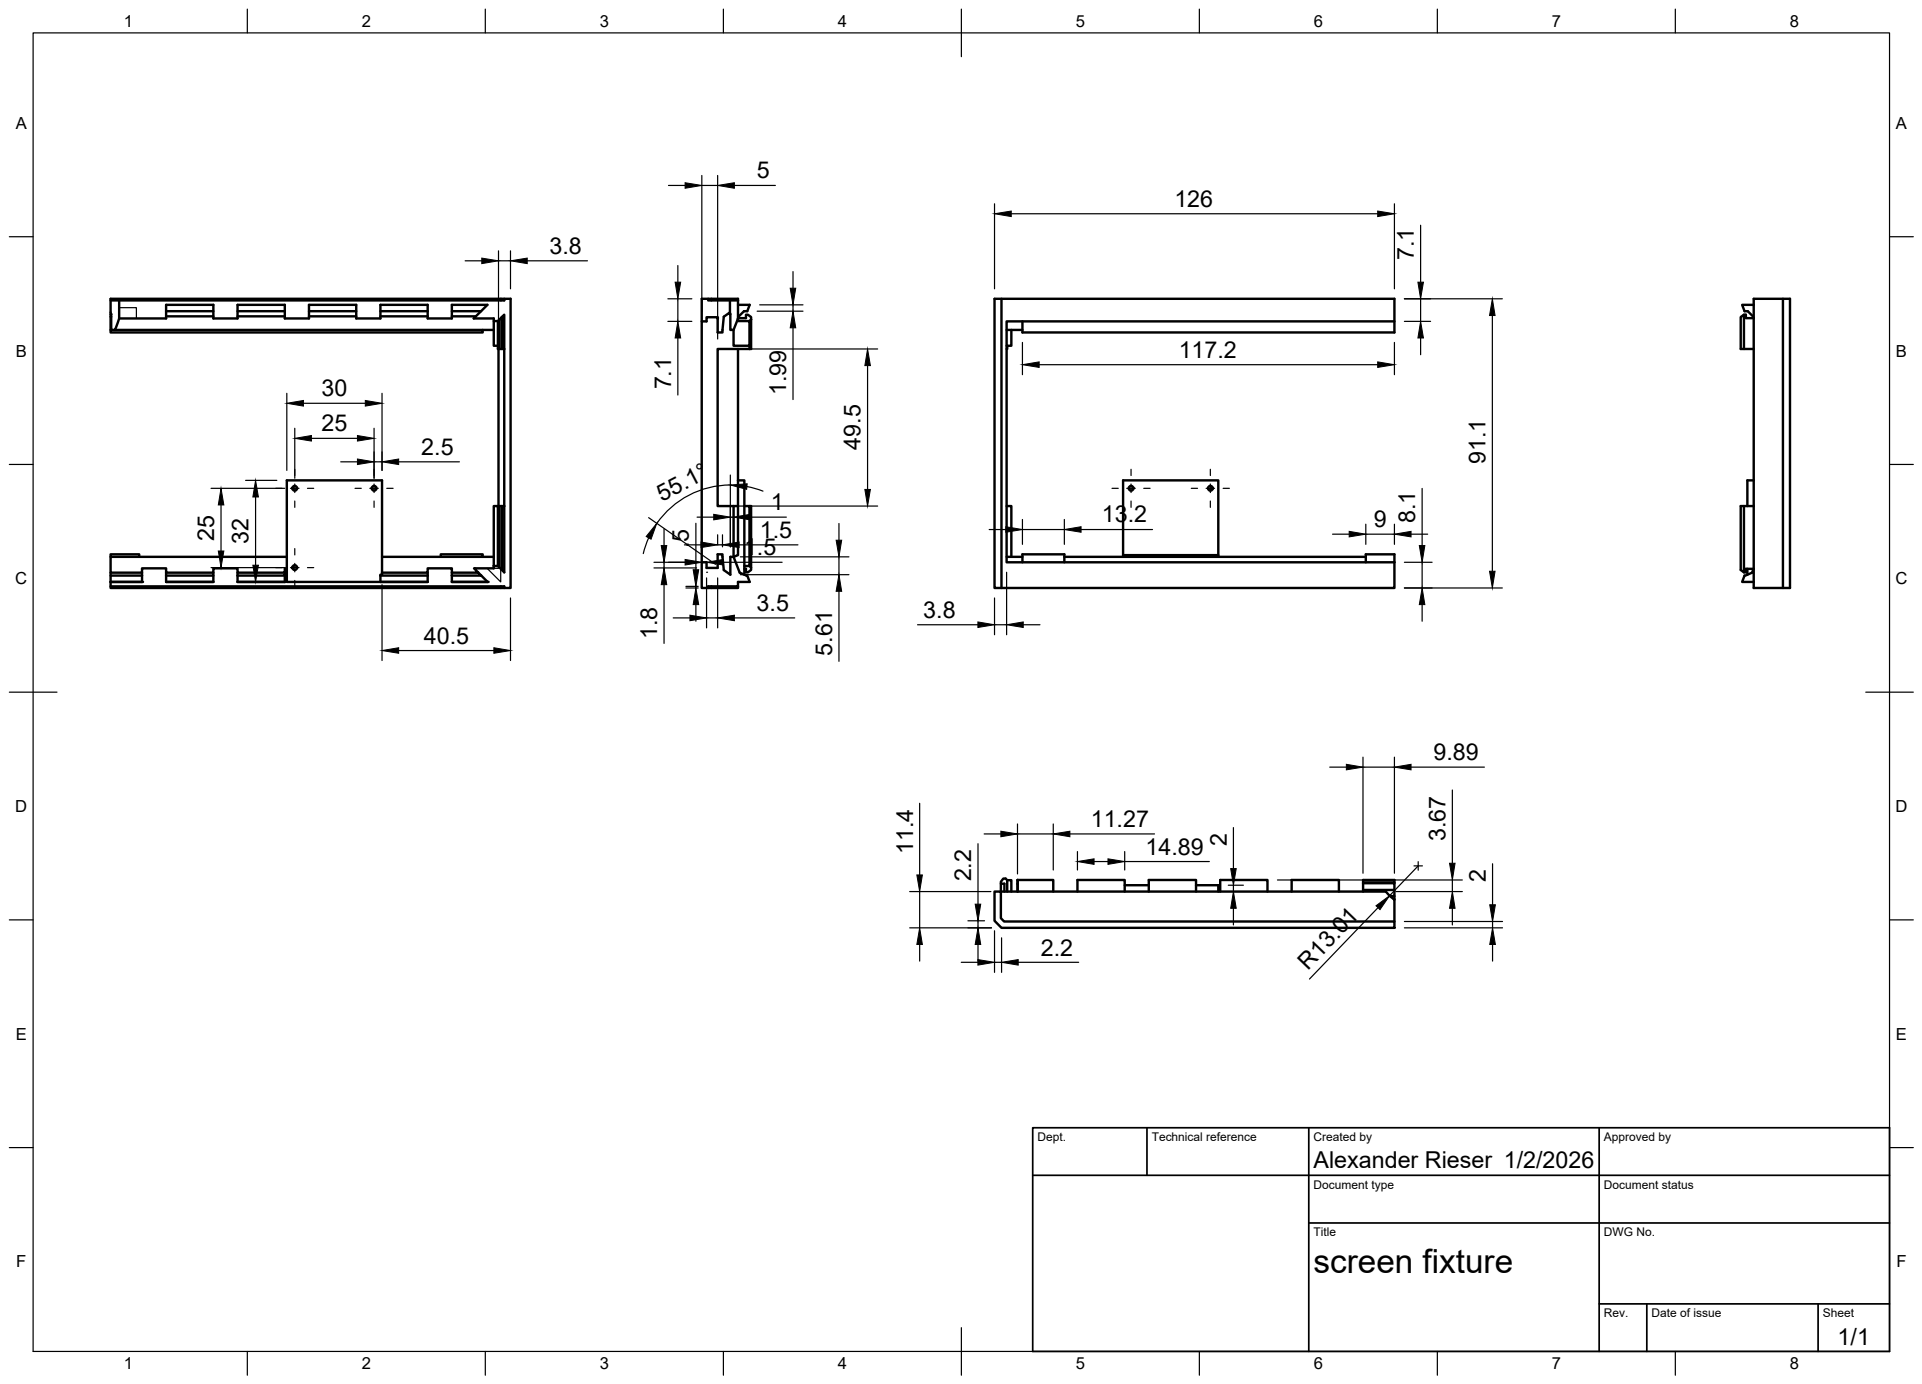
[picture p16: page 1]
Title; DWG No.; Rev.; Date of issue; Sheet; screen fixture

Dept. | Technical reference | Created by Alexander Rieser 1/2/2026 | Approved by

Document type | Document status

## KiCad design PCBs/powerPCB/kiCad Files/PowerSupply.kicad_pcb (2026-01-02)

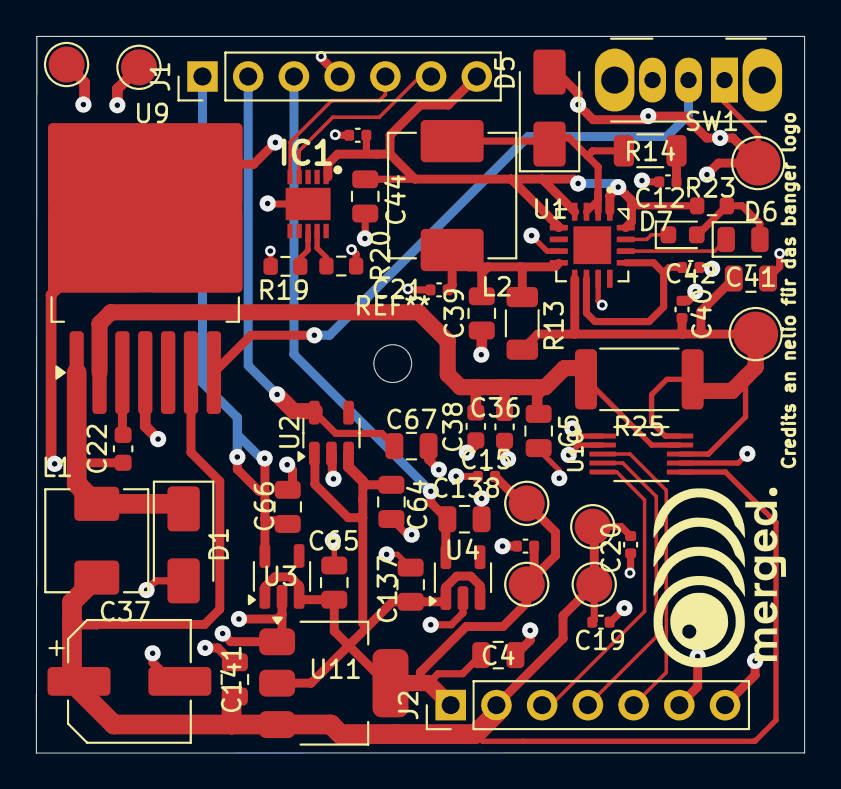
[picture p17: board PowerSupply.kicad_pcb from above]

Board: 2 copper layers, 42.7 x 39.8 mm, 56 parts (0 on the bottom side), 24 nets.

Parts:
C4, C5: 22uF; C_0805_2012Metric
C12, C15, C16, C19, C20, C21, C40, C42, C43: 0.1uF; C_0402_1005Metric
C22: 10nF; C_0603_1608Metric
C36, C38: 6.8uF; C_0603_1608Metric
C37: 180uF; CP_Elec_6.3x5.9
C39, C41, C44: 10uF; C_0805_2012Metric
C64, C65, C66, C67, C137, C138, C141: 1uF; C_0805_2012Metric
D1: SS38; D_SMA
D5: D_Filled; D_SMA
D6: LED; LED_0805_2012Metric
D7: LED; LED_0603_1608Metric
IC1: HUSB238; SON50P300X300X80-11N-D
J1, J2: Conn_01x07_Pin; PinHeader_1x07_P2.54mm_Vertical
L1: 4.7uH inductor; L_APV_APH0530
L2: 10uH; L_Changjiang_FXL0630
R13: 0.06Ohm; R_1206_3216Metric
R14: 3 Ohm; R_1206_3216Metric
R19: 10k; R_0603_1608Metric
R20: 7.5kOhm; R_0603_1608Metric
R23: 470Ohm; R_0603_1608Metric
R25: R_Shunt; R_2512_6332Metric
SW1: SW_DPST_x2; SW_Slide_SPDT_Angled_CK_OS102011MA1Q
TP10, TP18: battery testpoint; TestPoint_Pad_D2.5mm
TP13, TP14, TP16, TP17, TP19, TP20: TestPoint; TestPoint_Pad_D2.0mm
U1: TP5100; QFN65P400X400X90-17N
U2, U4: MICRONE(Nanjing Micro One Elec) ME6212C28M5G; SOT-23-5
U3: Diodes Incorporated AP2112K-1.8TRG1; SOT-23-5
U9: LM22678TJ-5.0/NOPB; TO-263-7_TabPin8
U10: INA226AIDGSR; SOP50P490X110-10N
U11: 5v to 3.3v converter; SOT-223-3_TabPin2

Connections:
+3.3V: C4.1, C15.1, C16.2, C64.2, C65.2, C137.2, J2.1, TP16.1, TP17.1, U2.1 (IN), U2.3 (EN), U3.1 (IN), U3.3 (EN), U4.1 (IN), U4.3 (EN), U11.2 (VO)
+5V: C19.1, C20.1, C37.1, C141.2, J2.2, L1.2, TP13.1, TP19.1, U9.7 (EN), U10.6 (VS), U11.3 (VI)
/1.5v out: C138.2, J1.3, U4.5 (OUT)
/1.8v out: C66.1, J1.1, U3.5 (OUT)
/2.8v out: C67.2, J1.2, U2.5 (OUT)
/CC1: IC1.4 (CC1), J1.6
/CC2: IC1.5 (CC2), J1.5
/USB+: C43.1, C44.1, IC1.1 (VIN), J1.7, R23.1, U1.1 (VIN), U1.4 (VIN), U1.5 (VIN), U1.16 (VIN)
/battery output: C5.1, C36.1, C38.1, R25.2, U9.3 (BOOT), U10.9 (IN-)
/power SCL: J2.3, U10.5 (SCL)
/power SDA: J2.4, U10.4 (SDA)
/voltage Alert Pin: J2.5, U10.3 (ALERT)
GND: C4.2, C5.2, C12.1, C12.2, C15.2, C16.1, C19.2, C20.2, C21.1, C21.2, C36.2, C37.2, C38.2, C39.1, C39.2, C40.2, C41.2, C42.2, C43.2, C44.2, C64.1, C65.1, C66.2, C67.1, C137.1, C138.1, C141.1, D1.2 (A), D5.2 (A), IC1.11 (GND), J1.4, J2.6, J2.7, L2.1, R13.1, R14.2, R19.2, R20.2, SW1.1 (A), TP14.1, TP18.1, TP20.1, U1.7 (GND), U1.8 (VS), U1.11 (TS), U2.2 (GND), U3.2 (GND), U4.2 (GND), U9.1 (SW), U9.8, U10.1 (A1), U10.2 (A0), U10.7 (GND), U11.1 (GND)
unnamed: C22.1, D1.1 (K), L1.1, U9.4 (GND)
unnamed: D5.1 (K), L2.2, R14.1, U1.2 (LX), U1.3 (LX)
unnamed: D6.2 (A), D7.2 (A), R23.2
unnamed: D6.1 (K), U1.14 (~STDBY)
unnamed: D7.1 (K), U1.15 (~CHRG)
unnamed: IC1.9 (ISET), R20.1
unnamed: IC1.8 (VSET), R19.1
unnamed: SW1.2 (B), U9.6 (FB)
unnamed: C40.1, C41.1, R13.2, R25.1, TP10.1, U1.9 (BAT), U10.8 (VBUS), U10.10 (IN+)
unnamed: C42.1, U1.10 (VREG), U1.13 (CS)
unnamed: C22.2, U9.2 (VIN)

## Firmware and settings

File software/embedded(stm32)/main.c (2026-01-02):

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

// all code written by me with minimal AI assistance, comments added using AI
// and verified by me

/* Includes ------------------------------------------------------------------*/
#include "main.h"
#include "usb_device.h"

/* USER CODE BEGIN Includes */
/* Includes ------------------------------------------------------------------*/
#include "main.h"                 // Cube-generated base header
#include "stm32h7xx.h"            // CMSIS core + device defines
#include "stm32h7xx_hal.h"        // Core HAL
#include "stm32h7xx_hal_cortex.h" // Core functions (NVIC, SysTick, etc.)
#include "stm32h7xx_hal_dcmi.h"   // DCMI camera interface
#include "stm32h7xx_hal_dma.h"    // DMA API
#include "stm32h7xx_hal_gpio.h"   // GPIO HAL (if not included in main.h)
#include "stm32h7xx_hal_i2c.h"    // I2C HAL
#include "stm32h7xx_hal_rcc.h"
#include "stm32h7xx_hal_rcc_ex.h" // <-- defines __HAL_RCC_DMAMUX1_CLK_ENABLE
#include "stm32h7xx_ll_bus.h"     // fallback LL clock enables

#include "usbd_cdc_if.h"
#include <stdbool.h> // for bool, true, false
#include <stdbool.h>
#include <stdint.h> // for uint8_t, uint32_t, etc.
#include <stdio.h>  // for printf, setvbuf
#include <string.h> // for memset, memcpy (optional)

/* USER CODE END Includes */


DCMI_HandleTypeDef hdcmi;
DMA_HandleTypeDef hdma_dcmi;

I2C_HandleTypeDef hi2c1;

/* USER CODE BEGIN PV */
#define OV5640_ADDR_8BIT (0x3C << 1) // OV5640 I2C address
#define REG_CHIP_ID_HIGH                                                       \
  0x300A // test variables for testing conneciton to camera
#define REG_CHIP_ID_LOW                                                        \
  0x300B // test variables for testing conneciton to
         // camera

#define MAX_REGISTRY_SIZE 256 // Reserved amount of memory for I2C writes map

// I2C adress changes map
typedef struct {
  uint16_t reg_addr;
  uint8_t val;
} OV5640_Reg_t;

// create I2C hash map
OV5640_Reg_t OV5640_Registry[MAX_REGISTRY_SIZE];
uint16_t OV5640_Registry_Count = 0;

// Helper to keep track if we have loaded defaults yet
bool defaults_loaded = false;
/* USER CODE END PV */

/* Private function prototypes generated by STM32IDE
 * -----------------------------------------------*/
void SystemClock_Config(void);
static void MPU_Config(void);
static void MX_GPIO_Init(void);
static void MX_DMA_Init(void);
static void MX_I2C1_Init(void);
static void MX_DCMI_Init(void);
void Registry_Set(uint16_t reg, uint8_t val);
void Registry_LoadDefaults(void);
void Registry_ApplyAll(void);
void Parse_USB_Command(char *cmd);
void Camera_LiveLoop(void);
/* USER CODE BEGIN PFP */

static uint32_t rx_index = 0;

DCMI_HandleTypeDef hdcmi; // global

uint8_t CDC_Transmit_HS(uint8_t *Buf, uint16_t Len);

#define CAM_RST_Port GPIOD
#define CAM_RST_Pin GPIO_PIN_0

#define CAM_PWDN_Port GPIOD
#define CAM_PWDN_Pin GPIO_PIN_1

#define N 1

#define W 320
#define H 240
#define BPP 2
#define FRAME_BYTES (W * H * BPP)
#define CHUNK_SIZE 4096 // 4KB chunks are safe for the HAL

/* ---- Use D1 AXI SRAM, not SDRAM ---- */
#undef FB_BASE_ADDR
#define FB_BASE_ADDR 0x30000000U // D2 SRAM1
uint8_t *const framebuf = (uint8_t *)FB_BASE_ADDR;
#define FB_BASE ((uint8_t *)FB_BASE_ADDR)

/* Optional: keep a 256 KB non-cacheable MPU window at 0x24000000 */
#define DMA_WIN_BASE 0x24000000U
#define DMA_WIN_SIZE MPU_REGION_SIZE_256KB

static inline void swo_put(uint8_t b) { ITM_SendChar(b); }

uint32_t words = FRAME_BYTES / 4;

volatile bool dcmi_stop_req = false;

volatile uint8_t camera_frame_ready = 0;
volatile uint8_t camera_error_flag = 0;

extern volatile uint8_t trigger_flag;
volatile uint8_t trigger_flag = 0;

volatile uint8_t usb_rx_buffer[64]; // Buffer to store incoming data
volatile uint8_t usb_rx_flag = 0; // Flag: 1 = New data arrived, 0 = No new data

static void MPU_Config(void);
static void MX_FMC_Init(void);
static void CameraI2Cinit(void);
static void Camerainit(void);
/* USER CODE END PFP */

/* USER CODE BEGIN 0 */

/**
 * @brief Initializes the Serial Wire Output (SWO) for ITM debugging.
 * @param swo_hz The desired frequency for the trace clock.
 */
static void SWO_Init(uint32_t swo_hz) {
  CoreDebug->DEMCR |= CoreDebug_DEMCR_TRCENA_Msk; // enable trace unit
  DBGMCU->CR |= (1U << 5); // TRACE_IOEN -> route TRACESWO

  // Force PB3 = TRACESWO (AF0)
  __HAL_RCC_GPIOB_CLK_ENABLE();
  GPIO_InitTypeDef GI = {0};
  GI.Pin = GPIO_PIN_3;
  GI.Mode = GPIO_MODE_AF_PP;
  GI.Pull = GPIO_NOPULL;
  GI.Speed = GPIO_SPEED_FREQ_VERY_HIGH;
  GI.Alternate = 0; // AF0 = JTDO/TRACESWO
  HAL_GPIO_Init(GPIOB, &GI);

  TPI->SPPR = 2; // NRZ/Async
  TPI->ACPR =
      (SystemCoreClock / swo_hz) - 1; // e.g. 99 for 2 MHz @ 200 MHz core
  TPI->FFCR = 0x100;

  ITM->LAR = 0xC5ACCE55;         // unlock (H7)
  ITM->TCR = ITM_TCR_ITMENA_Msk; // enable ITM
  ITM->TER = (1U << 0);          // port 0 on
}

int _write(int file, char *ptr, int len) {
  (void)file;
  for (int i = 0; i < len; i++)
    ITM_SendChar((uint32_t)ptr[i]);
  return len;
}

/**
 * @brief Performs a full hardware power-up and reset sequence for the OV5640
 * sensor.
 *
 * Controls the PWDN and RESET pins to ensure the sensor enters a clean state
 * according to the OmniVision power-on timing requirements.
 */
static void CamhardwareReset(void) {
  printf("[PWR] Proper power sequence start...\n");

  // Ensure sensor is in power-down before reset pulse
  HAL_GPIO_WritePin(CAM_PWDN_Port, CAM_PWDN_Pin,
                    GPIO_PIN_SET); // PWDN = 1 → sleep
  HAL_Delay(10);

  // Assert reset
  HAL_GPIO_WritePin(CAM_RST_Port, CAM_RST_Pin,
                    GPIO_PIN_RESET); // RESET = 0 → hold in reset
  HAL_Delay(10);

  // Power up
  HAL_GPIO_WritePin(CAM_PWDN_Port, CAM_PWDN_Pin,
                    GPIO_PIN_RESET); // PWDN = 0 → active mode
  HAL_Delay(5);

  // Release from reset
  HAL_GPIO_WritePin(CAM_RST_Port, CAM_RST_Pin, GPIO_PIN_SET); // RESET = 1 → run
  HAL_Delay(20);

  printf("[PWR] OV5640 released from reset & power-down.\n");
}

/**
 * @brief Writes an 8-bit value to a 16-bit register address on the OV5640.
 * @param reg 16-bit register address.
 * @param val 8-bit value to write.
 * @return HAL status.
 */
static HAL_StatusTypeDef cam_write_u8(uint16_t reg, uint8_t val) {
  uint8_t buf[3] = {(uint8_t)(reg >> 8), (uint8_t)reg, val};
  HAL_StatusTypeDef st =
      HAL_I2C_Master_Transmit(&hi2c1, OV5640_ADDR_8BIT, buf, 3, 100);
  printf("[I2C] W 0x%04X <- 0x%02X %s\r\n", reg, val,
         (st == HAL_OK) ? "OK" : "ERR");
  return st;
}

/**
 * @brief Reads an 8-bit value from a 16-bit register address on the OV5640.
 * @param reg 16-bit register address.
 * @param val Pointer to store the retrieved 8-bit value.
 * @return HAL status.
 */
static HAL_StatusTypeDef cam_read_u8(uint16_t reg, uint8_t *val) {
  uint8_t idx[2] = {(uint8_t)(reg >> 8), (uint8_t)reg};
  HAL_StatusTypeDef st;
  st = HAL_I2C_Master_Transmit(&hi2c1, OV5640_ADDR_8BIT, idx, 2, 100);
  if (st != HAL_OK) {
    printf("[I2C] W(reg) 0x%04X ERR\r\n", reg);
    return st;
  }
  st = HAL_I2C_Master_Receive(&hi2c1, OV5640_ADDR_8BIT, val, 1, 100);
  printf("[I2C] R 0x%04X -> 0x%02X %s\r\n", reg, *val,
         (st == HAL_OK) ? "OK" : "ERR");
  return st;
}

static inline void dcache_invalidate_fb(void) {
  uintptr_t a = ((uintptr_t)framebuf) & ~31u;
  size_t n = ((FRAME_BYTES + 31u) & ~31u) + 32u;
  SCB_InvalidateDCache_by_Addr((void *)a, n);
}

/**
 * @brief High-level live preview manager with host handshaking.
 *
 * Continuously captures frames and transmits them over USB. After each frame,
 * it waits for an acknowledgment ('A') or a stop command ('X') from the PC.
 * Includes periodic hardware resets to maintain sensor stability.
 */
void Camera_LiveLoop(void) {
  printf("--- ENTERING LIVE MODE (HANDSHAKE) ---\n");

  bool running = true;
  uint32_t frame_counter = 0; // 1. Initialize Frame Counter

  while (running) {
    // 2. CHECK RESET CONDITION (Every 10 frames)
    // We skip 0 so we don't reset immediately upon entering the mode.
    if (frame_counter > 0 && (frame_counter % 150 == 0)) {
      printf("Live Mode: %lu frames reached. Performing Periodic Reset...\n",
             (unsigned long)frame_counter);

      // Perform the full hardware/software reset sequence
      // This function (defined in USER CODE BEGIN 4) re-initializes DCMI,
      // I2C, and GPIOs
      Camera_Hard_Reset();

      // Note: Camera_Hard_Reset includes a delay (usually 1s) for sensor
      // stabilization.
    }

    // 3. CAPTURE
    Camera_CaptureOneFrame();

    // 4. CHECK FOR CAPTURE ERRORS
    if (camera_error_flag) {
      printf("Live Mode: Capture Error. Retrying...\n");
      HAL_Delay(10);
      continue;
    }

    // 5. SEND FRAME
    DumpFullFrame_USB();

    // 6. WAIT FOR CONFIRMATION (Handshake) with TIMEOUT
    usb_rx_flag = 0;
    bool waiting_for_ack = true;

    // Record the time immediately after sending
    uint32_t wait_start = HAL_GetTick();

    while (waiting_for_ack) {
      // --- TIMEOUT CHECK ---
      if ((HAL_GetTick() - wait_start) > 1000) {
        printf("Live Mode: TIMEOUT (No ACK for 1s). Exiting.\n");
        waiting_for_ack = false;
        running = false; // Stop the outer loop
        break;
      }

      // --- USB CHECK ---
      if (usb_rx_flag == 1) {
        char resp = (char)usb_rx_buffer[0];
        usb_rx_flag = 0;

        if (resp == 'A' || resp == 'a') {
          // ACK received -> Capture next frame
          waiting_for_ack = false;
        } else if (resp == 'X' || resp == 'x') {
          // STOP received -> Exit
          printf("Live Mode: Stop Received.\n");
          waiting_for_ack = false;
          running = false;
        }
      }
    }

    // 7. Increment counter only after a successful cycle
    if (running) {
      frame_counter++;
    }
  }

  printf("--- EXITING LIVE MODE ---\n");
}

/**
 * @brief Updates or adds a register value in the local OV5640 registry.
 *
 * This registry acts as a volatile cache of sensor settings, allowing the
 * firmware to re-apply specific configurations (like exposure or gain) after a
 * reset.
 *
 * @param reg 16-bit register address.
 * @param val 8-bit value.
 */
void Registry_Set(uint16_t reg, uint8_t val) {
  // 1. Search if register already exists (Linear search is fast enough for
  // <500 items)
  for (int i = 0; i < OV5640_Registry_Count; i++) {
    if (OV5640_Registry[i].reg_addr == reg) {
      // Found it! Update the value.
      OV5640_Registry[i].val = val;
      // printf("[REG] Updated 0x%04X to 0x%02X\n", reg, val);
      return;
    }
  }

  // 2. If not found, append to the end
  if (OV5640_Registry_Count < MAX_REGISTRY_SIZE) {
    OV5640_Registry[OV5640_Registry_Count].reg_addr = reg;
    OV5640_Registry[OV5640_Registry_Count].val = val;
    OV5640_Registry_Count++;
    // printf("[REG] Added 0x%04X = 0x%02X\n", reg, val);
  } else {
    printf("[REG] Error: Registry Full!\n");
  }
}

/**
 * @brief Iterates through the local registry and writes every entry to the
 * sensor.
 */
void Registry_ApplyAll(void) {
  printf("[REG] Applying %d registers...\n", OV5640_Registry_Count);
  for (int i = 0; i < OV5640_Registry_Count; i++) {
    cam_write_u8(OV5640_Registry[i].reg_addr, OV5640_Registry[i].val);
  }
  printf("[REG] Apply Complete.\n");
}

/**
 * @brief Loads the hardcoded default camera configuration into the local
 * registry.
 *
 * This includes PLL settings, windowing, output format (YUYV), and ISP tunings.
 */
void Registry_LoadDefaults(void) {
  // Clear existing
  OV5640_Registry_Count = 0;

  // --- SYSTEM & IO PAD CONTROL ---
  Registry_Set(0x3016, 0x00); // System Reset 02 (Not explicitly documented as
                              // 0x3016 likely Reserved/Reset related)
  Registry_Set(
      0x3017,
      0x7F); // IO Control: Pad Output Dir/Enable (PCLK, HREF, VSYNC, etc.)
  Registry_Set(0x3018, 0xFC); // IO Control: Pad Output Dir/Enable (D[9:0])
  Registry_Set(0x3019, 0x00); // Reserved / Internal Use
  Registry_Set(0x301A, 0x00); // Reserved / Internal Use
  Registry_Set(0x301B, 0x00); // Reserved / Internal Use
  Registry_Set(0x301C, 0x00); // Reserved / Internal Use
  Registry_Set(0x301D, 0x00); // Reserved / Internal Use
  Registry_Set(0x301E, 0x00); // Reserved / Internal Use
  Registry_Set(0x302C, 0xC2); // IO Pad Drive Strength (Misc Control)

  // --- PLL (System Clocks) ---
  Registry_Set(
      0x3034,
      0x18); // SC PLL CTRL0: MIPI bit mode (0x8=8bit, 0xA=10bit) / Charge Pump
  Registry_Set(0x3036, 0x69); // SC PLL CTRL2: PLL Multiplier (0x69 = 105)
  Registry_Set(0x3037, 0x13); // SC PLL CTRL3: PLL Root Divider / Pre-divider
  Registry_Set(0x3039, 0x00); // SC PLL CTRL5: PLL Bypass (0=Enable PLL)
  Registry_Set(0x3103, 0x03); // SCCB Control: System Clock (Bit 1=1 -> Use PLL)
  Registry_Set(0x303A, 0x00); // SC PLL CTRL 6 (Likely internal PLL fine tuning)
  Registry_Set(0x303B, 0x19); // SC PLL CTRL 7 (Likely internal PLL fine tuning)
  Registry_Set(0x303C, 0x11); // SC PLL CTRL 8 (Likely internal PLL fine tuning)
  Registry_Set(0x303D, 0x30); // SC PLL CTRL 9 (Likely internal PLL fine tuning)

  // --- WINDOWING & TIMING ---
  Registry_Set(0x3800, 0x00); // TIMING HS: X Address Start High Byte
  Registry_Set(0x3801, 0x01); // TIMING HS: X Address Start Low Byte
  Registry_Set(0x3802, 0x00); // TIMING VS: Y Address Start High Byte
  Registry_Set(0x3803, 0x00); // TIMING VS: Y Address Start Low Byte (Start Y=0)
  Registry_Set(0x3804, 0x0A); // TIMING HW: X Address End High Byte
  Registry_Set(0x3805, 0x3F); // TIMING HW: X Address End Low Byte (End X=2623)
  Registry_Set(0x3806, 0x07); // TIMING VH: Y Address End High Byte
  Registry_Set(0x3807, 0x9B); // TIMING VH: Y Address End Low Byte (End Y=1947)
  Registry_Set(0x3808, 0x01); // TIMING DVPHO: Output Width High Byte (320)
  Registry_Set(0x3809, 0x40); // TIMING DVPHO: Output Width Low Byte
  Registry_Set(0x380A, 0x00); // TIMING DVPVO: Output Height High Byte (240)
  Registry_Set(0x380B, 0xF0); // TIMING DVPVO: Output Height Low Byte
  Registry_Set(0x380C, 0x07); // TIMING HTS: Total Horizontal Size High Byte
  Registry_Set(0x380D, 0x68); // TIMING HTS: Total Horizontal Size Low Byte
  Registry_Set(0x380E, 0x03); // TIMING VTS: Total Vertical Size High Byte
  Registry_Set(0x380F, 0xD8); // TIMING VTS: Total Vertical Size Low Byte
  Registry_Set(0x3810, 0x00); // TIMING HOFFSET: ISP Horizontal Offset High Byte
  Registry_Set(
      0x3811,
      0x10); // TIMING HOFFSET: ISP Horizontal Offset Low Byte (16 pixels)
  Registry_Set(0x3812, 0x00); // TIMING VOFFSET: ISP Vertical Offset High Byte
  Registry_Set(0x3813,
               0x06); // TIMING VOFFSET: ISP Vertical Offset Low Byte (6 lines)
  Registry_Set(0x3814,
               0x31); // TIMING X INC: Horizontal Subsample (Odd/Even increment)
  Registry_Set(0x3815,
               0x31); // TIMING Y INC: Vertical Subsample (Odd/Even increment)
  Registry_Set(0x3816, 0x00); // TIMING VSYNC DELAY (Low)
  Registry_Set(0x3817, 0x00); // TIMING VSYNC DELAY (High)
  Registry_Set(0x3818, 0x00); // TIMING HSYNC DELAY (Low)
  Registry_Set(0x3819, 0x00); // TIMING HSYNC DELAY (High)
  Registry_Set(0x3820,
               0x41); // TIMING TC REG20: Vertical Flip Enable (Bit 1=0, Bit
                      // 2=1?? Check logic, usually Bit 1/2 control flips)
  Registry_Set(0x3821,
               0x07); // TIMING TC REG21: ISP Mirror (Bit 2), Sensor Mirror (Bit
                      // 1), Horizontal Binning (Bit 0) - All ON (0x07) or OFF
                      // depending on exact bit meaning here.

  // --- OUTPUT FORMAT ---
  Registry_Set(
      0x4300,
      0x30); // FORMAT CONTROL 00: YUV422 (Bit 7:4=3), Order YUYV (Bit 3:0=0)
  Registry_Set(0x4301, 0x01); // FORMAT CONTROL 01: Data Sequence (Bit 1:0 = 01
                              // -> U/V from first pixel)
  Registry_Set(0x501F, 0x00); // FORMAT MUX CONTROL: Select ISP YUV422 (0x00)
  Registry_Set(0x4600, 0x80); // VFIFO CTRL00: JPEG Enable (Bit 5)? 0x80 usually
                              // implies a reset or specific block enable.

  // --- ISP & SCALING ---
  Registry_Set(0x5602, 0x40); // SCALE CTRL 2: X Scale High Byte? (Specifics
                              // depend on scaling algorithm used)
  Registry_Set(0x5604, 0x40); // SCALE CTRL 4: Y Scale High Byte?
  Registry_Set(
      0x5000,
      0x07); // ISP CONTROL 00: RAW Gamma (Bit 5), BPC (Bit 2), WPC (Bit 1), CIP
             // (Bit 0). 0x07 enables CIP, WPC, BPC. (Gamma OFF here?)
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
int main(void) {
  /* MPU
   * Configuration--------------------------------------------------------*/

  MPU_Config();

  /* MCU
   * Configuration--------------------------------------------------------*/

  SCB_EnableICache();
  SCB_EnableDCache();

  /* Reset of all peripherals, Initializes the Flash interface and the
   * Systick.
   */
  HAL_Init();
  SystemClock_Config();
  MX_DMA_Init();
  MX_GPIO_Init();
  MX_I2C1_Init();
  MX_USB_DEVICE_Init();

  SWO_Init(2000000);

  printf("started\n");

  Camerainit();
  __HAL_DCMI_ENABLE_IT(&hdcmi, DCMI_IT_FRAME | DCMI_IT_LINE | DCMI_IT_OVR |
                                   DCMI_IT_ERR);
  HAL_Delay(200);

  /* USER CODE BEGIN WHILE */
  while (1) {
    if (usb_rx_flag == 1) {
      // 1. CLEAR FLAG IMMEDIATELY
      usb_rx_flag = 0;

      // 2. CREATE A LOCAL COPY
      char local_cmd[64];
      memcpy(local_cmd, (char *)usb_rx_buffer, 64);
      local_cmd[63] = '\0';

      printf("RX: %s\n", local_cmd);

      // 4. PARSE COMMANDS
      if (local_cmd[0] == 'S') {
        FullCapture();
      } else if (local_cmd[0] == 'L') { // <--- ADD THIS BLOCK
        // Enter the blocking Live Loop
        Camera_LiveLoop();
      } // <--- END ADDITION
      else if (local_cmd[0] == 'R') {
        Camera_Hard_Reset();
      } else if (local_cmd[0] == 'W' || local_cmd[0] == 'w') {
        // ... existing Write logic ...
        uint32_t reg_in, val_in;
        int items = sscanf(local_cmd + 1, "%x %x", (unsigned int *)&reg_in,
                           (unsigned int *)&val_in);

        if (items == 2) {
          printf("PARSED: Reg=0x%04X Val=0x%02X\n", (uint16_t)reg_in,
                 (uint8_t)val_in);
          Registry_Set((uint16_t)reg_in, (uint8_t)val_in);
        } else {
          printf("ERROR: Bad W format. Got %d items.\n", items);
        }
      }
    }
  }
  /* USER CODE END WHILE */
}

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
/* USER CODE BEGIN 4 */
/**
 * @brief Performs a full system reset of both the hardware and peripheral
 * states.
 */
void Camera_Hard_Reset(void) {
  printf("--- STARTING HARD RESET ---\r\n");

  // 1. STOP DCMI & DMA
  // This halts any ongoing transfer and aborts the DMA stream
  HAL_DCMI_Stop(&hdcmi);

  // Optional: Explicitly De-Initialize DCMI to clear internal flags/states
  // HAL_DCMI_DeInit(&hdcmi);
  // MX_DCMI_Init(); // You must re-call the CubeMX generated init if you
  // DeInit

  Camerainit();
  // 4. FLUSH USB BUFFERS (Optional)
  // Ensure no junk data is sitting in the USB transmit buffer
  // CDC_Transmit_FS((uint8_t*)"READY", 5);

  printf("--- RESET COMPLETE ---\r\n");
}
/* USER CODE END 4 */

/* MPU Configuration */

void MPU_Config(void) {
  MPU_Region_InitTypeDef MPU_InitStruct = {0};

  /* Disables the MPU */
  HAL_MPU_Disable();

  /** Initializes and configures the Region and the memory to be protected
   */
  MPU_InitStruct.Enable = MPU_REGION_ENABLE;
  MPU_InitStruct.Number = MPU_REGION_NUMBER0;
  MPU_InitStruct.BaseAddress = 0x0;
  MPU_InitStruct.Size = MPU_REGION_SIZE_4GB;
  MPU_InitStruct.SubRegionDisable = 0x87;
  MPU_InitStruct.TypeExtField = MPU_TEX_LEVEL0;
  MPU_InitStruct.AccessPermission = MPU_REGION_NO_ACCESS;
  MPU_InitStruct.DisableExec = MPU_INSTRUCTION_ACCESS_DISABLE;
  MPU_InitStruct.IsShareable = MPU_ACCESS_SHAREABLE;
  MPU_InitStruct.IsCacheable = MPU_ACCESS_NOT_CACHEABLE;
  MPU_InitStruct.IsBufferable = MPU_ACCESS_NOT_BUFFERABLE;

  HAL_MPU_ConfigRegion(&MPU_InitStruct);
  /* Enables the MPU */
  HAL_MPU_Enable(MPU_PRIVILEGED_DEFAULT);

  /* Configure D2 SRAM (0x30000000) as Shareable/Non-Cacheable for USB DMA */
  MPU_InitStruct.Enable = MPU_REGION_ENABLE;
  MPU_InitStruct.Number = MPU_REGION_NUMBER1; // Use a different number than
                                              // your background region
  MPU_InitStruct.BaseAddress = 0x30000000;    // Address of RAM_D2
  MPU_InitStruct.Size =
      MPU_REGION_SIZE_32KB; // Or 256KB, depending on your linker
  MPU_InitStruct.SubRegionDisable = 0x0;
  MPU_InitStruct.TypeExtField = MPU_TEX_LEVEL0;
  MPU_InitStruct.AccessPermission = MPU_REGION_FULL_ACCESS;
  MPU_InitStruct.DisableExec = MPU_INSTRUCTION_ACCESS_ENABLE;
  MPU_InitStruct.IsShareable = MPU_ACCESS_SHAREABLE;
  MPU_InitStruct.IsCacheable = MPU_ACCESS_NOT_CACHEABLE; // <--- CRITICAL
  MPU_InitStruct.IsBufferable = MPU_ACCESS_BUFFERABLE;

  HAL_MPU_ConfigRegion(&MPU_InitStruct);
}

/**
 * @brief  This function is executed in case of error occurrence.
 * @retval None
 */
void Error_Handler(void) {
}
#ifdef USE_FULL_ASSERT
/**
 * @brief  Reports the name of the source file and the source line number
 *         where the assert_param error has occurred.
 * @param  file: pointer to the source file name
 * @param  line: assert_param error line source number
 * @retval None
 */
void assert_failed(uint8_t *file, uint32_t line) {
}
#endif /* USE_FULL_ASSERT */

// all code written by me with minimal AI assistance, comments added using AI
// and verified by me

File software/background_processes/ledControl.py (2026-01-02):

# ------------------ CLI entry point ------------------
"""
WS2812 LED effects for Raspberry Pi 5 using rpi5_ws2812.

This script provides several visual effects for a WS2812 LED strip connected to
the Raspberry Pi 5. It manages a background process state using a PID file to
ensure only one effect runs at a time and provides a CLI for triggering effects.

Includes effects: rainbow, comet, theater, solid, and white.
"""

#all code written by me with minimal AI assistance, comments added using AI and verified by me

from rpi5_ws2812.ws2812 import Color, WS2812SpiDriver
import time
import math
from typing import List, Tuple

import os
import signal

PID_FILE = "/tmp/led_effect.pid"

def _read_pid():
    """Reads the process ID of the currently running LED effect from the PID file."""
    try:
        with open(PID_FILE, "r") as f:
            return int(f.read().strip())
    except Exception:
        return None

def _pid_alive(pid: int) -> bool:
    """Checks if a process with the given PID is currently active."""
    try:
        os.kill(pid, 0)
        return True
    except OSError:
        return False

def _terminate_previous(timeout: float = 2.0) -> None:
    """Attempts to terminate any previously running LED effect process."""
    pid = _read_pid()
    if not pid:
        return
    # Don't kill ourselves if we happen to run within the same process
    if pid == os.getpid():
        return
    try:
        os.kill(pid, signal.SIGTERM)
    except ProcessLookupError:
        pass
    # wait up to timeout
    import time as _t
    start = _t.time()
    while _t.time() - start < timeout:
        if not _pid_alive(pid):
            break
        _t.sleep(0.05)
    if _pid_alive(pid):
        try:
            os.kill(pid, signal.SIGKILL)
        except ProcessLookupError:
            pass
    # best effort cleanup
    try:
        os.remove(PID_FILE)
    except Exception:
        pass

# ------------------ Config ------------------
LED_COUNT = 30
SPI_BUS = 0
SPI_DEVICE = 0

RGB = Tuple[int, int, int]

# ------------------ Helpers ------------------

def make_strip(led_count: int = LED_COUNT,
               spi_bus: int = SPI_BUS,
               spi_device: int = SPI_DEVICE):
    """
    Initializes the WS2812 strip and creates a local RGB buffer.

    Returns:
        tuple: (WS2812 strip object, RGB buffer list)
    """
    strip = WS2812SpiDriver(spi_bus=spi_bus, spi_device=spi_device,
                            led_count=led_count).get_strip()
    buf: List[RGB] = [(0, 0, 0)] * led_count
    return strip, buf


def show(strip, buf: List[RGB]) -> None:
    """Updates the physical LED strip with the contents of the RGB buffer."""
    for i, (r, g, b) in enumerate(buf):
        strip.set_pixel_color(i, Color(r, g, b))
    strip.show()


def clear(buf: List[RGB]) -> None:
    """Resets the RGB buffer to all zeros (off)."""
    for i in range(len(buf)):
        buf[i] = (0, 0, 0)


def fade_all(buf: List[RGB], amount: int) -> None:
    """Reduces the brightness of all pixels in the buffer by a specific amount."""
    amt = max(0, int(amount))
    for i, (r, g, b) in enumerate(buf):
        buf[i] = (max(0, r - amt), max(0, g - amt), max(0, b - amt))


def wheel(pos: int) -> RGB:
    """Generates a color from a 0-255 position on a color wheel."""
    pos %= 256
    if pos < 85:
        return (pos * 3, 255 - pos * 3, 0)
    if pos < 170:
        pos -= 85
        return (255 - pos * 3, 0, pos * 3)
    pos -= 170
    return (0, pos * 3, 255 - pos * 3)

# ------------------ Effects (3) ------------------

def effect_rainbow(strip, buf: List[RGB], fps: int = 50) -> None:
    """Runs a moving rainbow effect across the entire strip."""
    offset = 0
    frame = 1.0 / max(1, fps)
    n = len(buf)
    while True:
        t0 = time.time()
        for i in range(n):
            buf[i] = wheel((i * 256 // n + offset) & 255)
        show(strip, buf)
        offset = (offset + 2) & 255
        dt = time.time() - t0
        if dt < frame:
            time.sleep(frame - dt)


def effect_comet(strip, buf: List[RGB], fps: int = 60,
                  color: RGB = (0, 255, 180), fade: int = 18) -> None:
    """Runs a bouncing single pixel 'comet' effect with a fading tail."""
    n = len(buf)
    pos, direction = 0, 1
    frame = 1.0 / max(1, fps)
    while True:
        t0 = time.time()
        fade_all(buf, fade)
        buf[pos] = color
        show(strip, buf)
        pos += direction
        if pos <= 0 or pos >= n - 1:
            direction *= -1
        dt = time.time() - t0
        if dt < frame:
            time.sleep(frame - dt)


def effect_theater_chase(strip, buf: List[RGB], fps: int = 30,
                          color: RGB = (255, 80, 0), gap: int = 3) -> None:
    """Runs a classic 'theater chase' marquee effect."""
    step = 0
    frame = 1.0 / max(1, fps)
    n = len(buf)
    g = max(1, gap)
    while True:
        t0 = time.time()
        # Clear for crisp dots
        for i in range(n):
            buf[i] = (0, 0, 0)
        for i in range(step % g, n, g):
            buf[i] = color
        show(strip, buf)
        step = (step + 1) % g
        dt = time.time() - t0
        if dt < frame:
            time.sleep(frame - dt)

def effect_solid_color(strip, buf: List[RGB], color: RGB) -> None:
    """Displays a constant solid color across the entire strip."""
    while True:
        for i in range(len(buf)):
            buf[i] = color
        show(strip, buf)
        time.sleep(0.05)


# ------------------ New Effect: White ------------------
def effect_white(strip, buf: List[RGB], brightness: int = 200) -> None:
    """Gradually ramps up and then holds a solid white light."""
    brightness = max(0, min(255, int(brightness)))
    target_color = (brightness, brightness, brightness)
    ramp_duration = 0.7
    steps = max(1, int(ramp_duration / 0.02))
    sleep_per_step = ramp_duration / steps 

    # Smooth ramp to the target brightness once, then hold steady.
    for step in range(1, steps + 1):
        level = int(brightness * step / steps)
        color = (level, level, level)
        for i in range(len(buf)):
            buf[i] = color
        show(strip, buf)
        time.sleep(sleep_per_step)

    while True:
        for i in range(len(buf)):
            buf[i] = target_color
        show(strip, buf)
        time.sleep(0.05)

# ------------------ Registry & single-effect runner ------------------
EFFECTS = {
    "rainbow": effect_rainbow,
    "comet": effect_comet,
    "theater": effect_theater_chase,
    "solid": effect_solid_color,
    "white": effect_white,
}
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

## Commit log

2026-01-02 Add README for portable stereoscopic wigglegram camera
    This README details the design and development of a portable stereoscopic wigglegram camera, including its features, system architecture, and software stack.
2026-01-02 Fix formatting in README.md
    Removed extra newline before the Sensors section.
2026-01-18 new sample images
